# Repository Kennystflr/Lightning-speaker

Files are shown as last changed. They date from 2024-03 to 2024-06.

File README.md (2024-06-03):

# Lightning-speaker
Project of Kenny Saint Fleur, Mathys Minsac, Lavallee Alexandre, Florian Bonnet--Galand and Victor Morel. 1st Year ENSEA students.
Design of the electronic board for a speaker.
Using a STM32 microcontroller, audio codec and two class D amplifiers.

The purpose of this project is to design the electronic of a speaker. More specifically the goal is to take an entry signal from Jack 6.35 mm connector and to have sound coming out of a stereo loudspeaker. 
We could also have a parametric eq using 2 encoders 1 for the gain and 1 for the frequency we would be changing.
We also want to have the system working on battery with Usb-C power delivery to charge-up the battery and power up the system even if there is no battery connected.

There is a schematic of the projects detailed review on this repository's root. projectSchematics

Basically, we would be calcultating coeficients for the SGTL5000 audio codec with the STM32 from the encoder's command. We can command up to 4 different filters with this method.
Then we would apply filters to the audio codec by sending the filter's coeficients through I2C communication protocol to the SGTL5000.
About the signal itself, it would enter into the audio codec, pass through the filters, be transmitted to the STM32 using I2S communication protocol and then would go through the Half Bridge Class D audio amplifer.
To charge up the battery, the 9V power supply (negociated with a source by the STM32) goes through a BMS who can bypass the battery in case it is dead or missing.

An issue we have met doing this was that the Half bridge was commuting between a positive voltage and ground which was a bad for the loudspeakears as the load. To resolve that we had to cut the rms continuous voltage 
using a genuinely calculated capacity.

As IC references we have :
-Microprocessor : STM32G491CET6
-Audio codec :SGTL5000XNLA3
-Battery Management System : BQ25306RTET
- USB-C protection IC : TCPP01-M12
- USB protection IC : USBLC6-2SC6
- Mosfet driver : UCC27325DR
- LDO 5V : AZ1117-5.0
- LDO 3.3V : BU33SD5WG-TR
- LDO 1.8V : BU18SD5WG-TRe

Unfortunately, the project wouldn't work in the end and we weren't able to debug it before the due time.
So we came up with a lifeboat plan of showing off our secondary board :

Project Specifications for the Replacement Project (aims to test the different codes made during the project and the PCB secondary board):

To test the LEDs, the potentiometer, and the encoder button, the LEDs are lit one by one, faster or slower depending on the value of the potentiometer.
The button on encoder 1 allows the LEDs to light up in the opposite direction.

To test the RGB (even though we only use 2 out of 3 LEDs) and the rotation of the encoder, the brightness of the red LED of encoder 2 is increased while the brightness of the blue LED is decreased when encoder 1 is rotated in one direction and vice versa when rotated in the other direction.

As a bonus, pressing the button on encoder 1 toggles the green LED of encoder 1 on or off.

*There is an demonstration video on the repository's root* : FinalProjetDemo

To push the project further we could have :
- had a bluetooth connection with a phone app to control the features.
- used the USB-C port's FS USB connected to the STM32 to have had sound going into the loudspeaker from an extern device as a computer or even a smartphone...

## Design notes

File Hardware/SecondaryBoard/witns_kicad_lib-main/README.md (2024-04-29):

# WITNS Kicad Library

## Add to your project
```bash
git submodule add git@github.com:lfiack/witns_kicad_lib.git
```

## Don't forget to document your project
Add the following lines to your README.md :
````
## Make the project work
This project uses a submodule for the KiCAD library. To get it properly, use the `--recursive` option when cloning the repo :

```bash
git clone --recursive git@github.com:<path_to_your_project>
```

If you forgot the `--recursive` option (as I do quite often), you can type the following command :

```bash
git submodule update --init --recursive
```
````

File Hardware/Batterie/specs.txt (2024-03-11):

CODEC : "SGTL5000" : 3.3 V.
STM32 : "STM32G491CET6" : 3.3 V.
Mosfet driver : "UCC2732x" : 5 V.

2 Batteries 18650 de 3.6V ; 2500 mAh. -> 7.2 V
En série.
Battery Management System : puce "BQ25306".

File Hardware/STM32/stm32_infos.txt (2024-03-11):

Choix de la puce SMT32g491cet6.
On en a besoin pour implémenter pas mal de choses à la fois et l'on a qu'un format LQFP32 soit 32 pins.
On implémente dans la puce :
 - USB C power delivery
 - Encondage des potentiometres de réglage du codec en hexadecimal.
 - Renvoie des réglages potentiomètre vers le codec en protocole I2C.
 - Reception du signal audio modifié par le codec via le protocole I2S.
 - Sortie PWM du signal du codec Vers l'etage amplificateur avec un Timer.

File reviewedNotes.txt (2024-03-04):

Fabriquer une carte électronique pour remplacer celle du speaker de base (+ de prises Jack).
On a 2 haut parleur 2 Ohm 15W dans un caisson avec un ruban led (dont on ne connaît pas les spécificités )

Sous-systèmes :
A)Amplificateur audio -> Class-D -> mosfet drivers
B) CODEC Audio 
C)Circuit de charge de la batterie 7.2V (2* [3.6V,2600mAh] en série ) <- voir si on double le nombre de batteries pour les mettre en parallèle
D) Circuit pour le ruban led.

//////////////////////////////////////////////////////////////////////////////////////////////////////
Sous-système A : 
Avoir 1 jack 3.5 et un jack 6.35 en entrée
On a deux speakers 2 Ohm en parallèle donc une charge de 1 Ohms.
Donc à 15 W, V_Load_Max = 7,75V # V_Bat
Pour faire fonctionner les diffénents composants de l'amplificateur (Mosfet driver,Timer 555, AOPs ...), on a besoin d'un régulateur de tension 5V d'où le LM7805.

Etage Schématisé, reste a vérifier les valeurs des composants, puis à les choisir.
//////////////////////////////////////////////////////////////////////////////////////////////////////
 Sous-Système B :
Pour appliquer des modifications au signal analogique d'entrée, on utilise le CODEC Audio SGTL5000. On utilisera les features d'equalisation (PEQ ou GEQ), controle du niveau de volume et bass boost.

//////////////////////////////////////////////////////////////////////////////////////////////////////
Sous-système C : 
La batterie est pour l'instant composée de deux cellules 18650(3.6V, 2600mAh) en série.
Charge USB C -> Puce Power delivery : TPS25730 + BMS IC : BQ25798 
on mettra juste un port usb c avec tout ça.

//////////////////////////////////////////////////////////////////////////////////////////////////////
Sous-système D :
Voir technologie Neopixel : https://github.com/berndoJ/libneopixel32/tree/master

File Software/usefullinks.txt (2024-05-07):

Flash memory to store the settings between use of the speaker :
https://www.st.com/resource/en/product_training/STM32G4-Memory-Flash_FLASH.pdf

Examples of USB C power Delivery implementation :
https://github.com/STMicroelectronics/STM32CubeG4/tree/master/Projects/B-G474E-DPOW1/Applications/USB-PD/USB-PD_Consumer_1port
https://www.youtube.com/watch?v=-vsJhNIaHxE

SGTL5000 audio codec implementation :
https://github.com/PaulStoffregen/Audio/blob/master/control_sgtl5000.cpp#L977

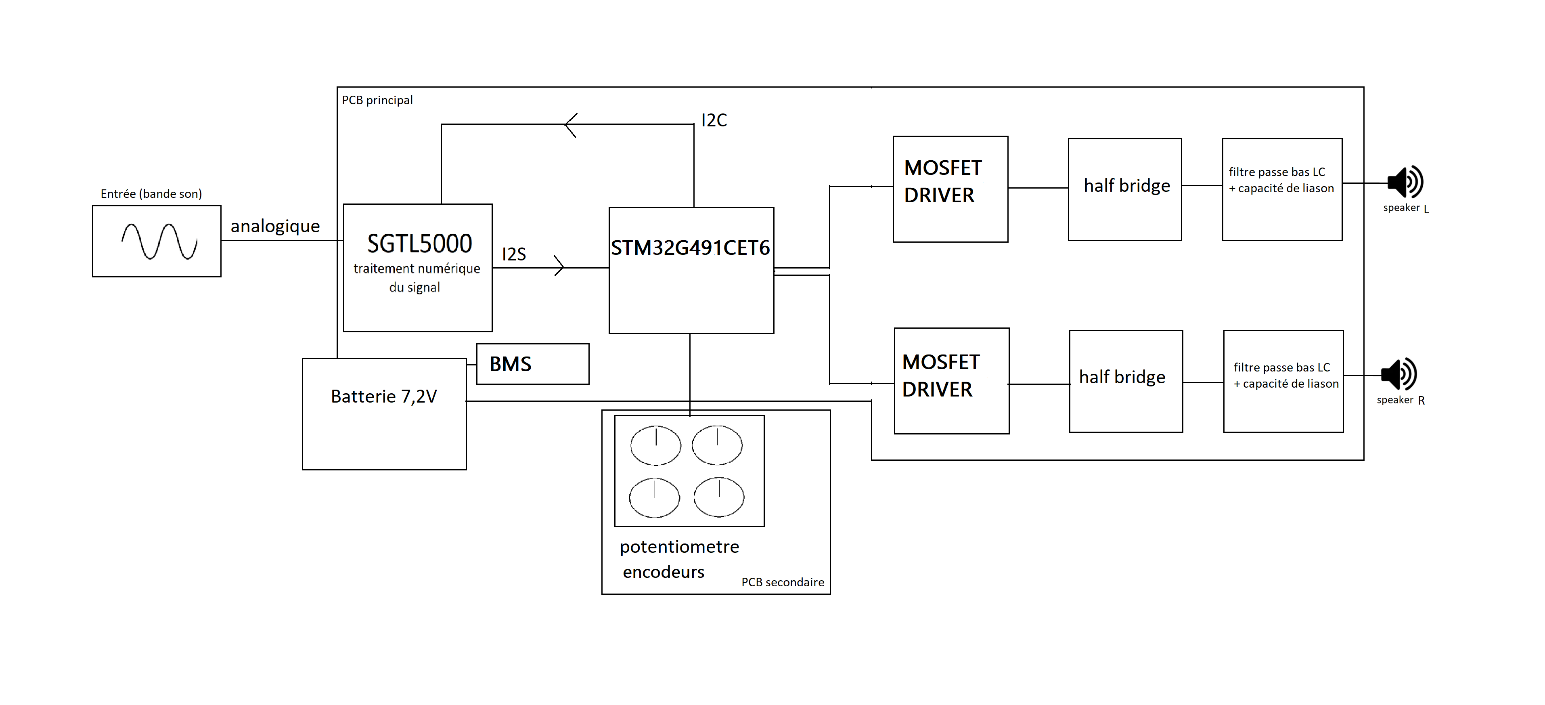
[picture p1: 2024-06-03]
projectSchematics.png

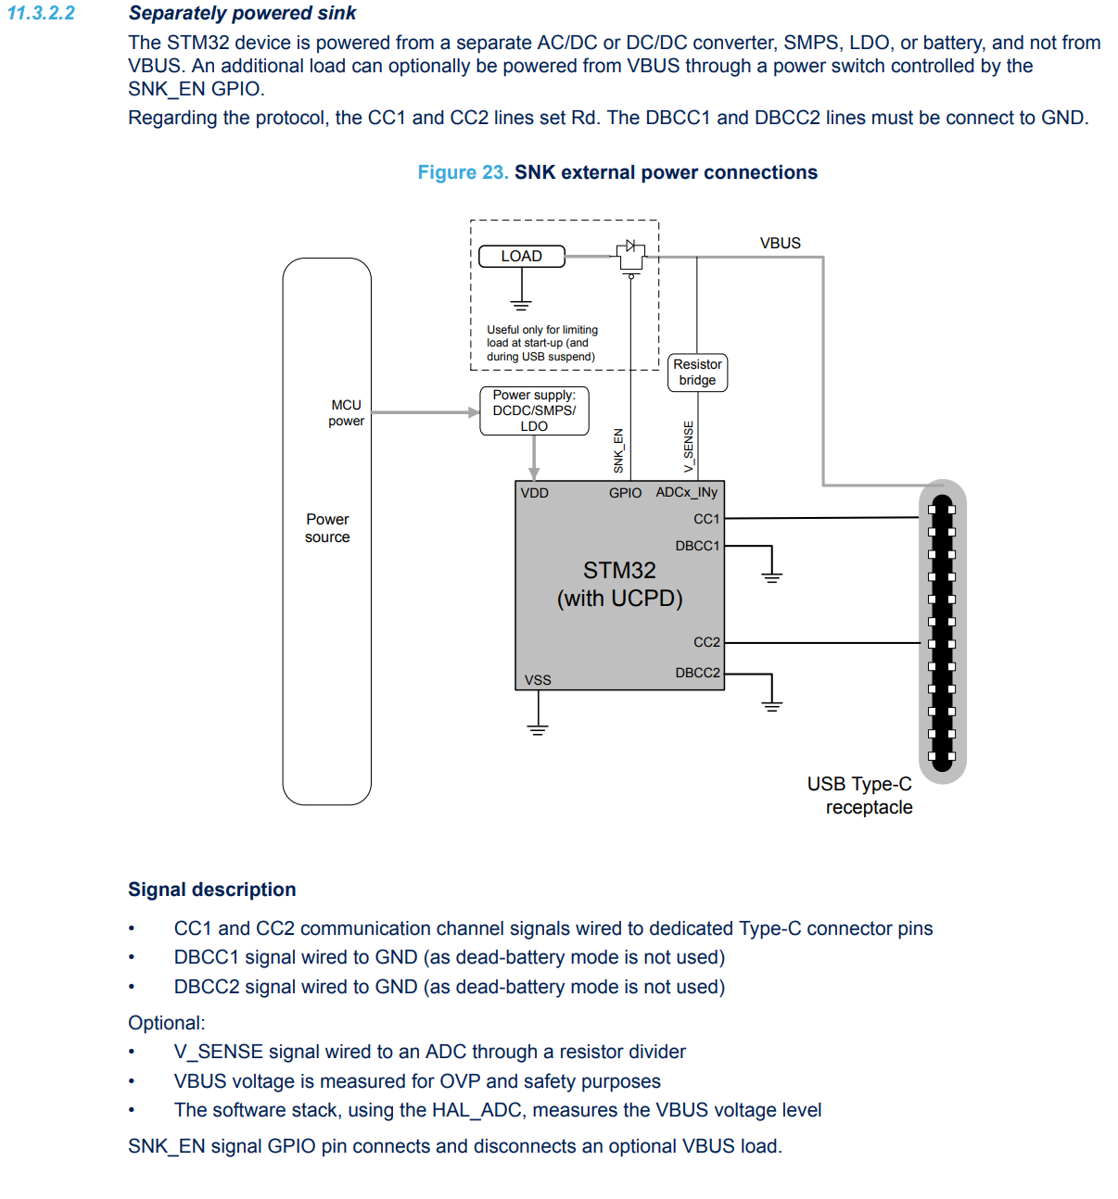
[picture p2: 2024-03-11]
Hardware/Batterie/USBCPD/Schematic.PNG

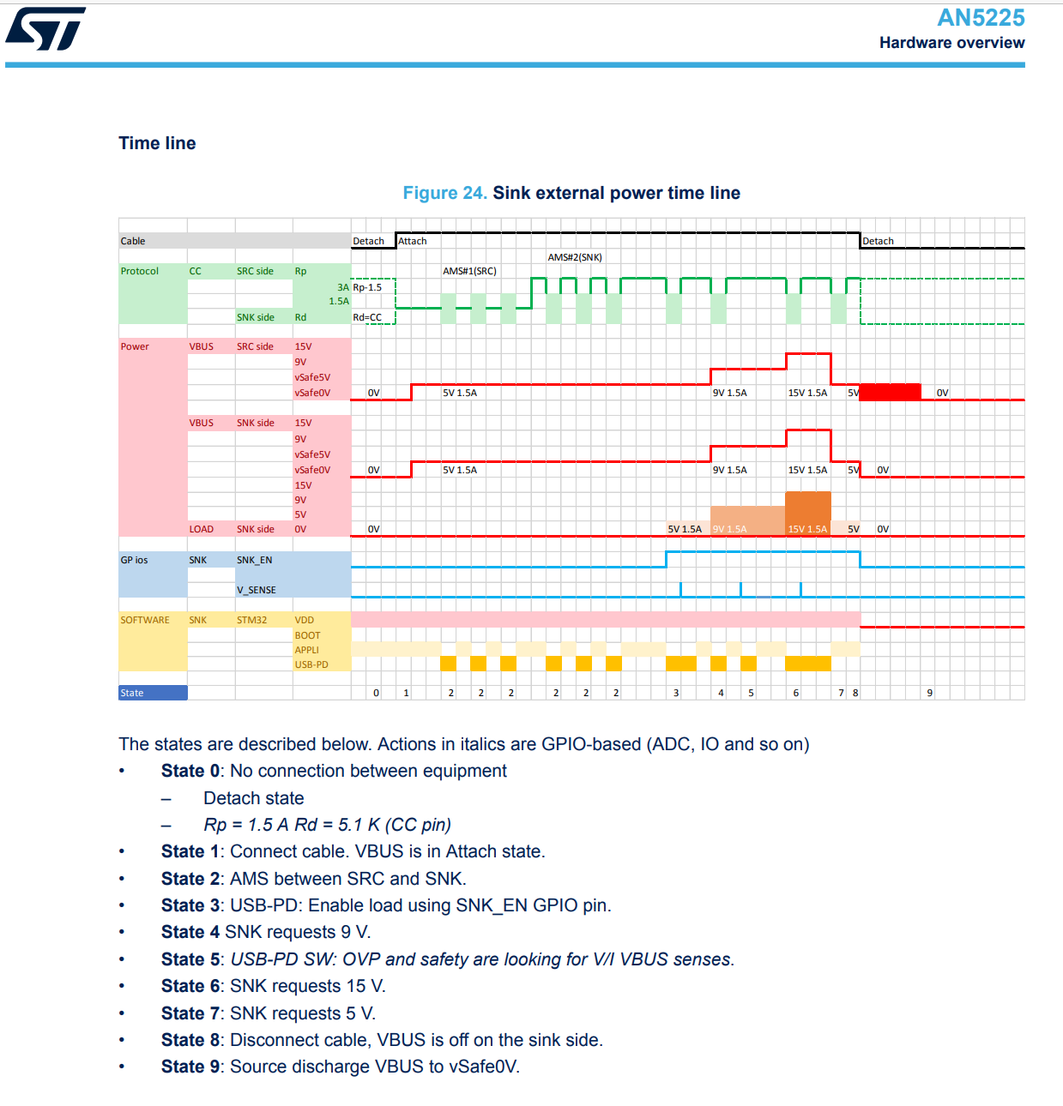
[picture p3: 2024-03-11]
Hardware/Batterie/USBCPD/states.PNG

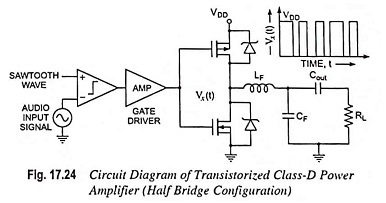
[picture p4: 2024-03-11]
Hardware/Circuit-Diagram-of-Transistorized-Class-D-Power-Amplifier-Half-Bridge-Configuration-02.jpg

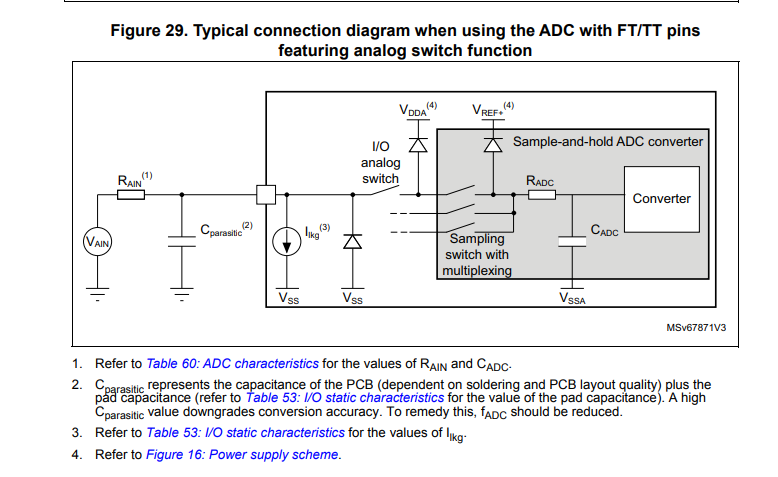
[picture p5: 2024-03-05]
Hardware/Potentiometre/SchémaSTM32p132.PNG

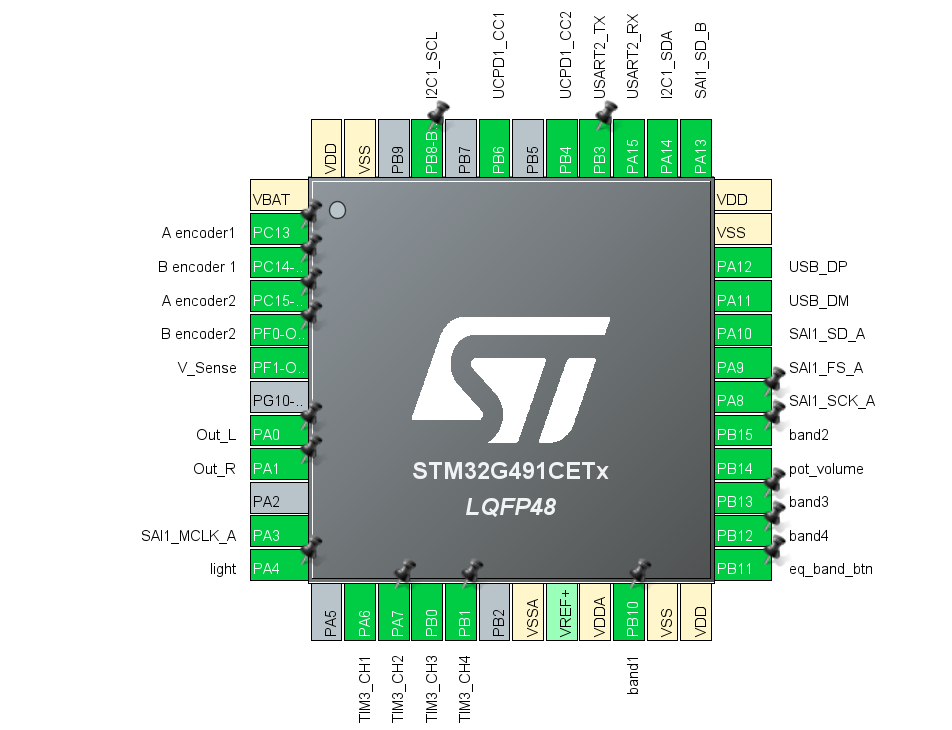
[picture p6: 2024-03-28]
Hardware/STM32/FinalPinout.PNG

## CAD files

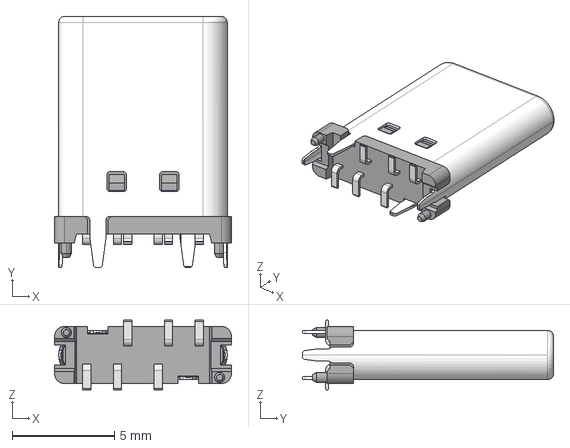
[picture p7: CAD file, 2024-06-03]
Hardware/Mainboard Final/footprints/USB4180-03-0120-C_REVA.step
8.66 x 12.3 x 3.40 mm

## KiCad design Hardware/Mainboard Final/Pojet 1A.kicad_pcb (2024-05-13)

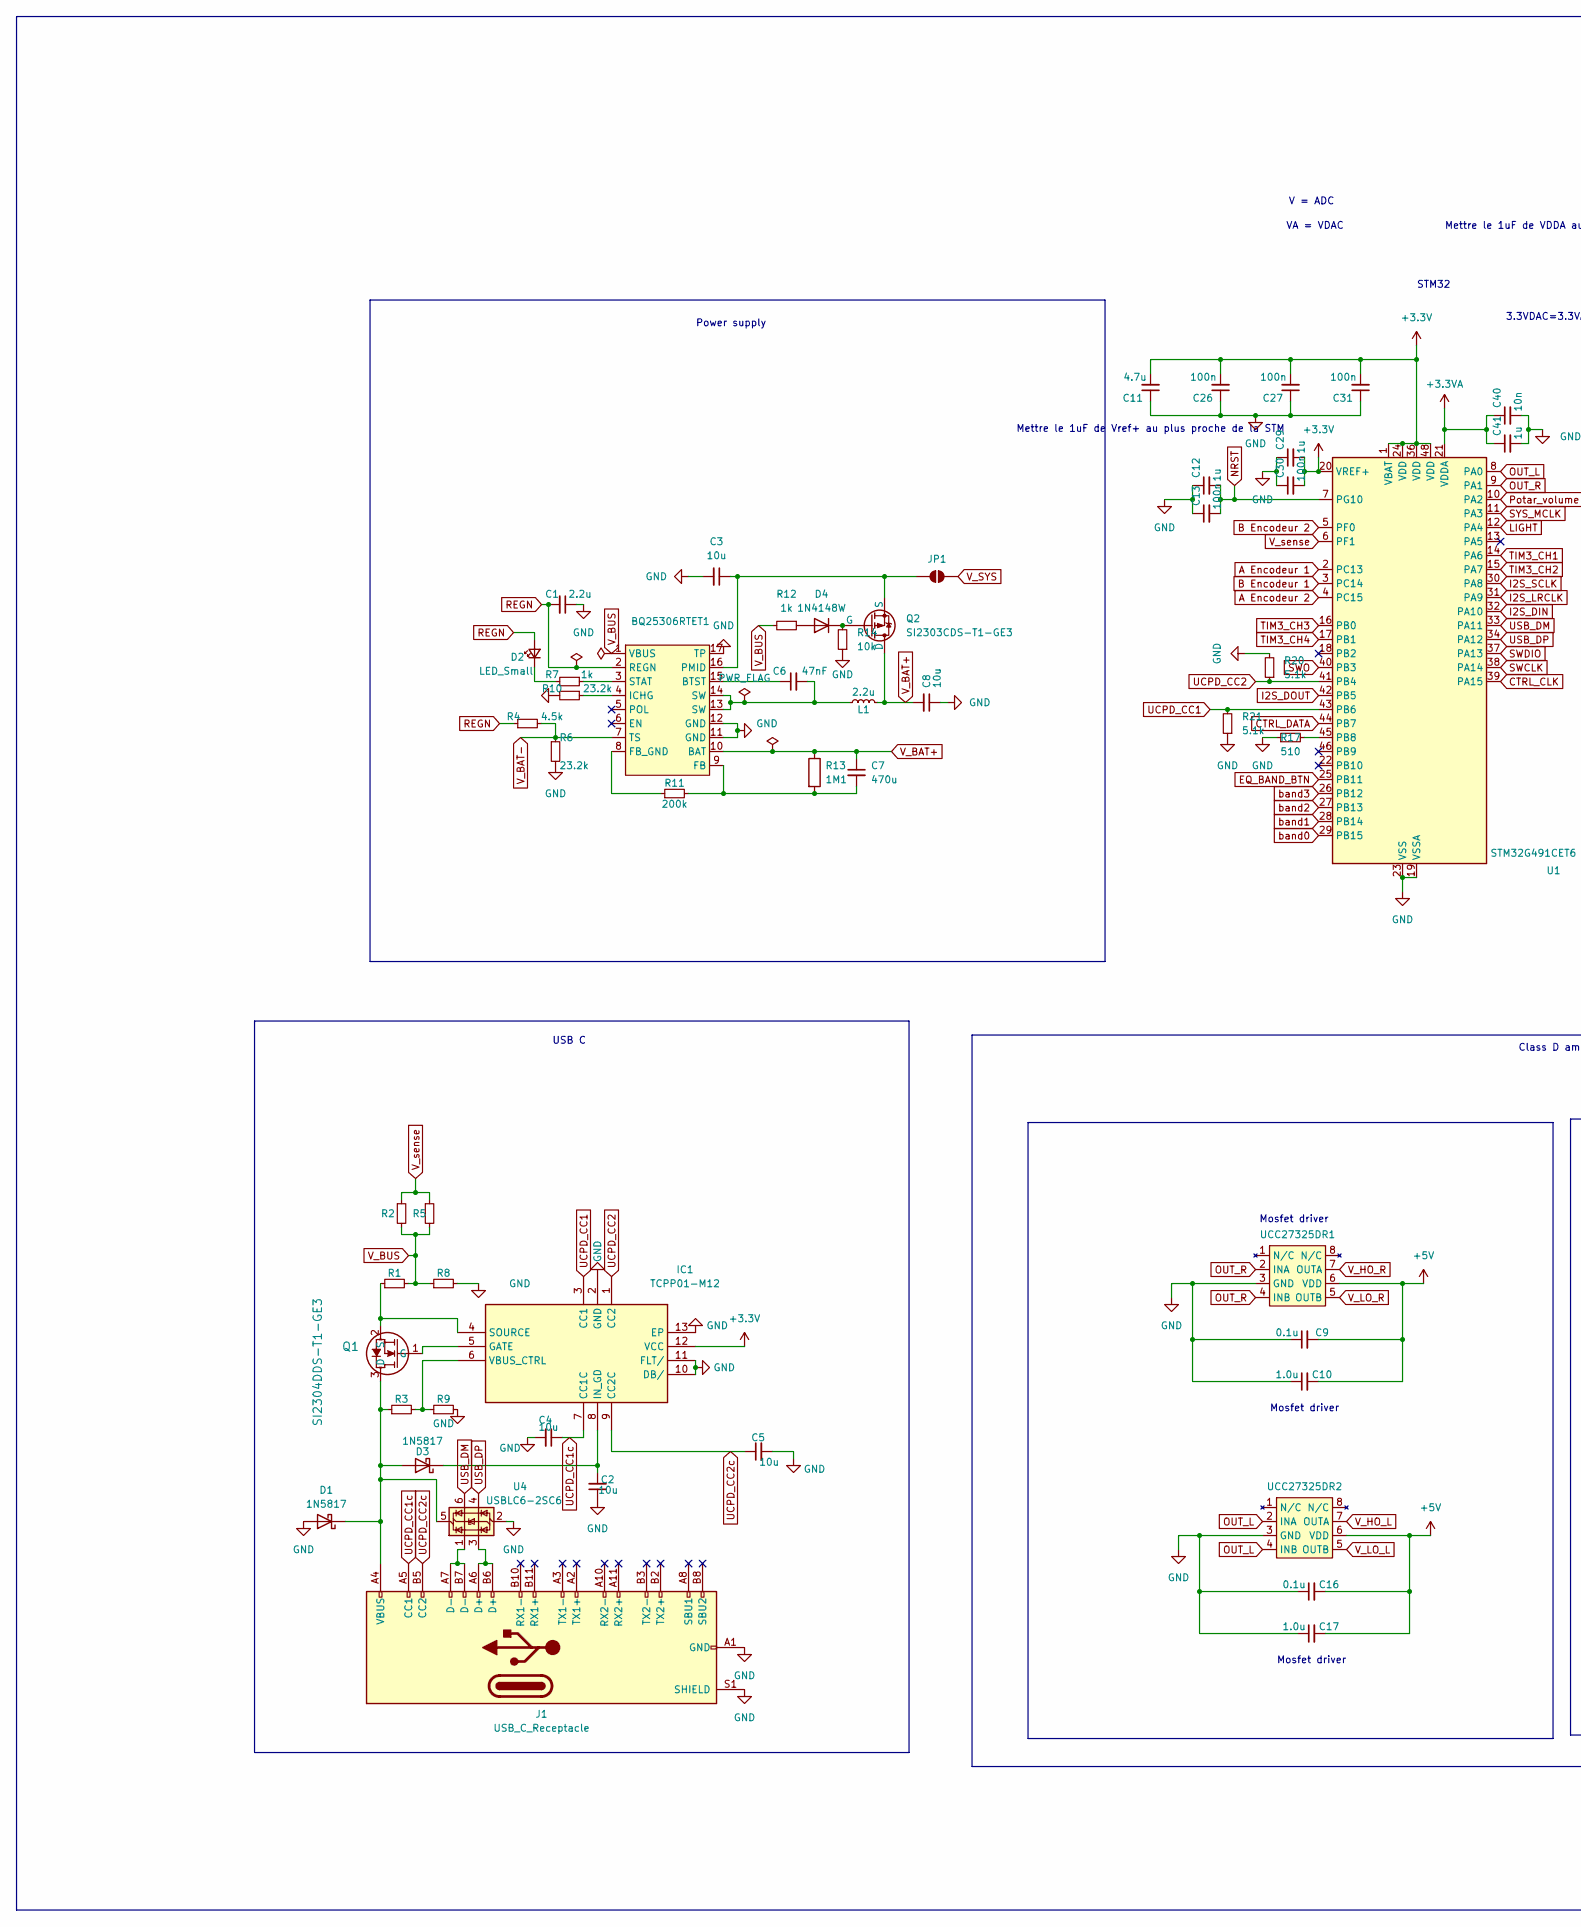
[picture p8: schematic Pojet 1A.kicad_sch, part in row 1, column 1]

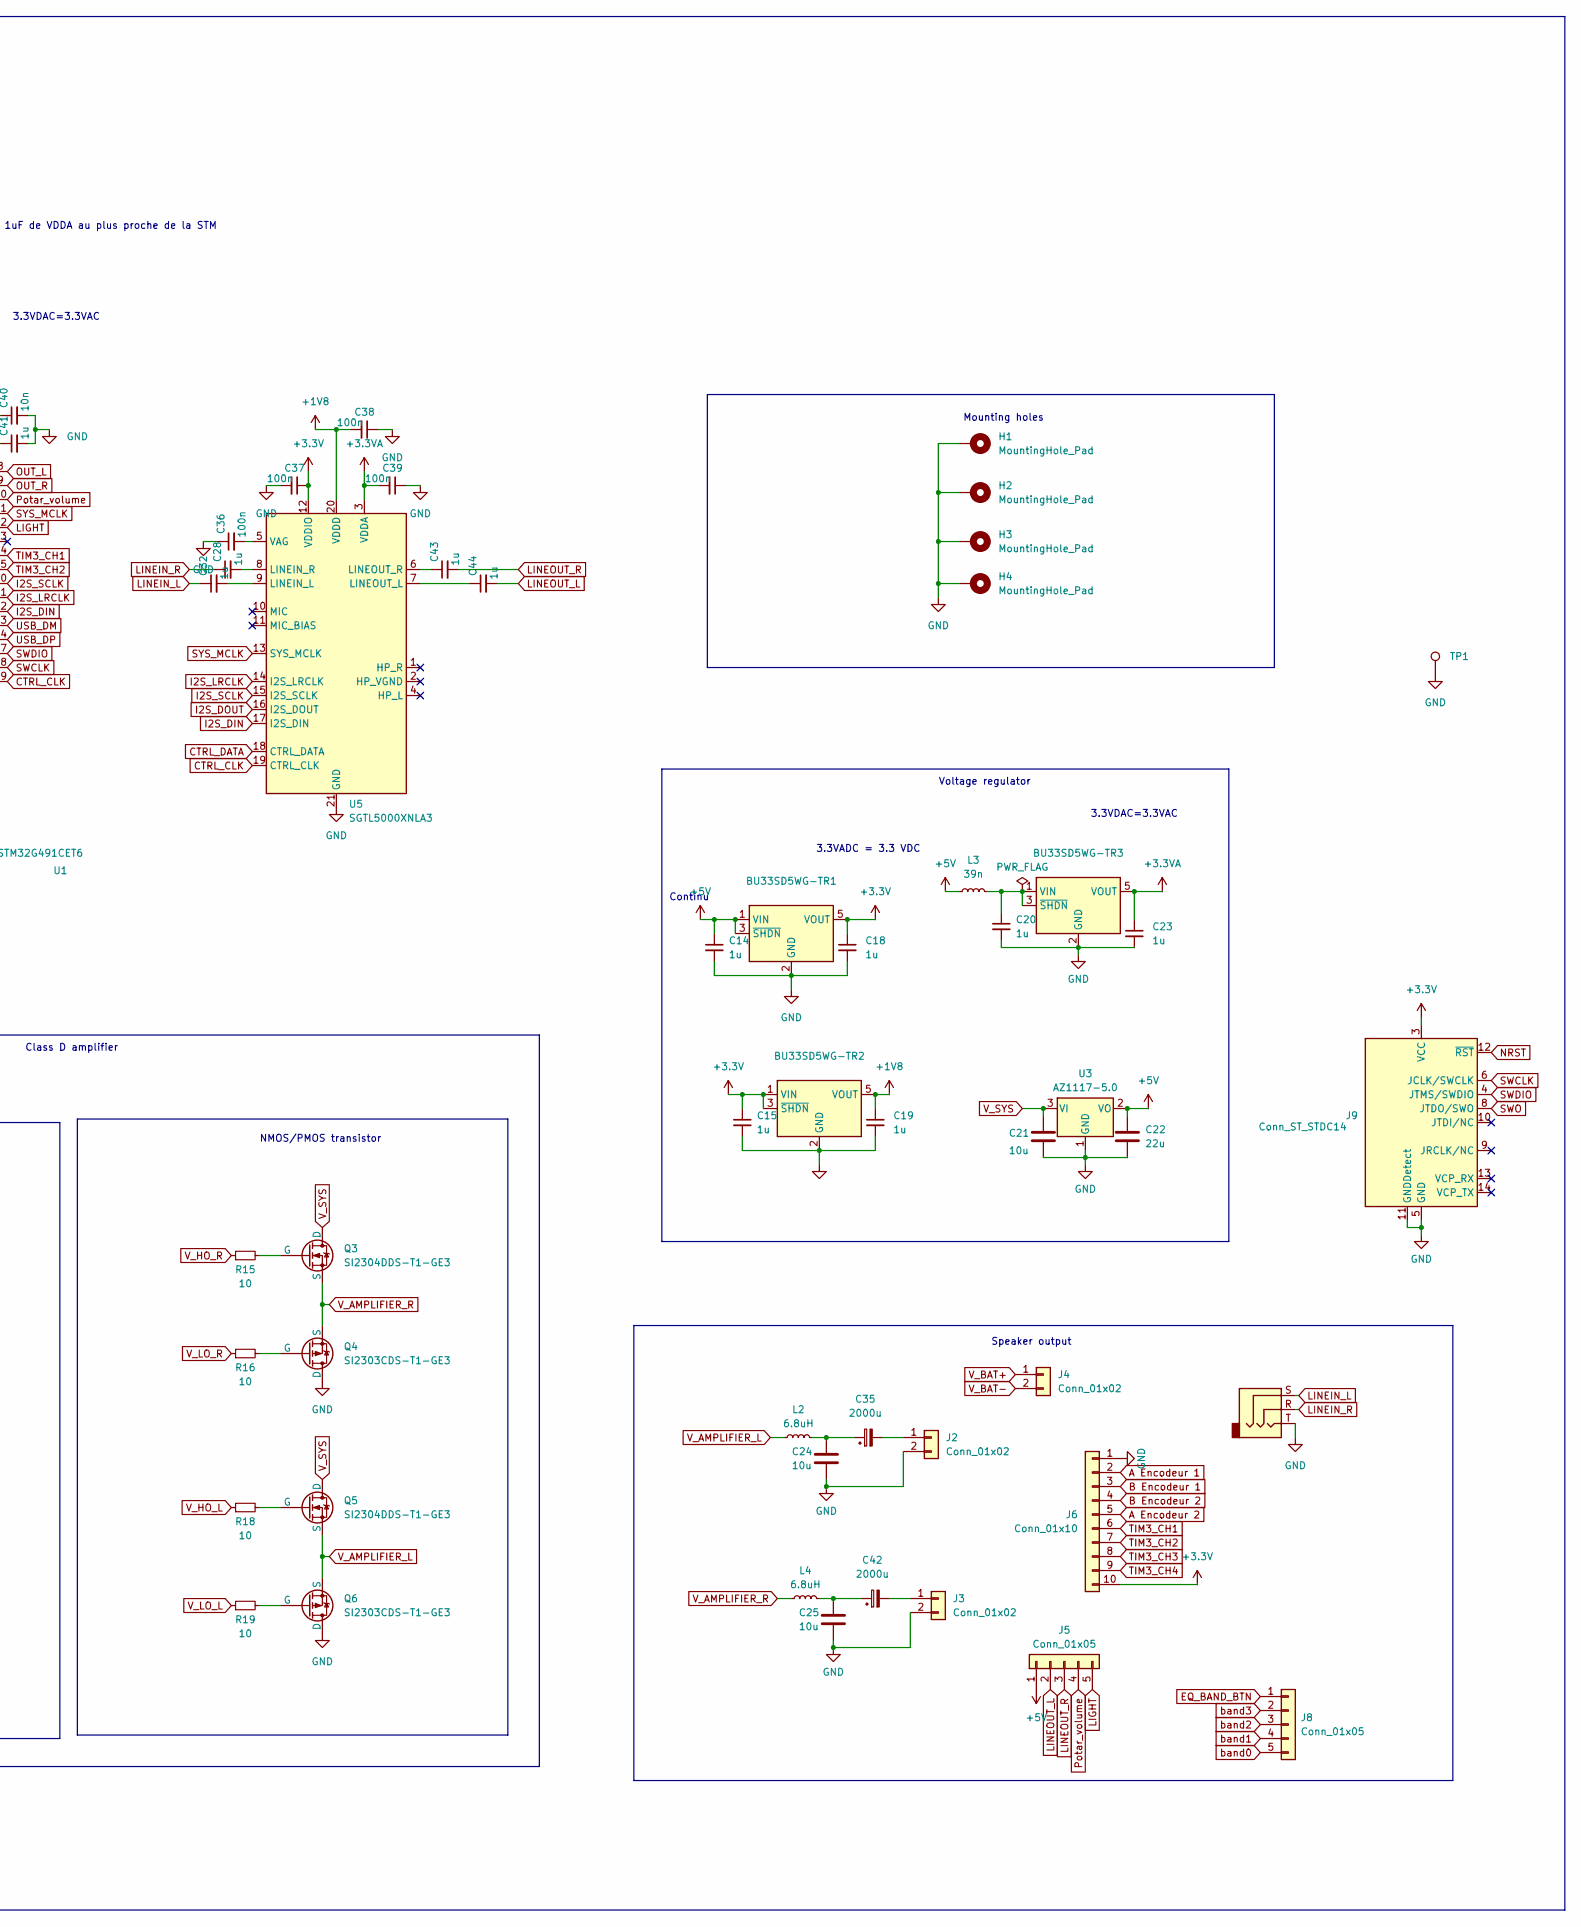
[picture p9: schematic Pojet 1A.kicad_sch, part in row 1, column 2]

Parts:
BQ25306RTET1: WQFN-16-1EP_3x3mm_P0.5mm_EP1.75x1.75mm
BU33SD5WG-TR1, BU33SD5WG-TR2, BU33SD5WG-TR3: LM1117DT-3.3; SOT-23-5
C1: 2.2u; C_0603_1608Metric_Pad1.08x0.95mm_HandSolder
C2, C3, C4, C5, C8, C24, C25: 10u; C_0402_1005Metric_Pad0.74x0.62mm_HandSolder
C6: 47nF; C_0603_1608Metric_Pad1.08x0.95mm_HandSolder
C7: 470u; C_0603_1608Metric_Pad1.08x0.95mm_HandSolder
C9, C16: 0.1u; C_0603_1608Metric_Pad1.08x0.95mm_HandSolder
C10, C17: 1.0u; C_0603_1608Metric_Pad1.08x0.95mm_HandSolder
C11: 4.7u; C_0603_1608Metric_Pad1.08x0.95mm_HandSolder
C12, C14, C15, C18, C19, C20, C23, C28, C29, C32, C41, C43, C44: 1u; C_0603_1608Metric_Pad1.08x0.95mm_HandSolder
C13, C26, C27, C30, C31, C36, C37, C38, C39: 100n; C_0402_1005Metric_Pad0.74x0.62mm_HandSolder
C21: 10u; C_0603_1608Metric_Pad1.08x0.95mm_HandSolder
C22: 22u; C_0805_2012Metric_Pad1.18x1.45mm_HandSolder
C35, C42: 2000u; CP_Radial_D10.0mm_P5.00mm
C40: 10n; C_0402_1005Metric_Pad0.74x0.62mm_HandSolder
D1, D3: 1N5817; D_DO-41_SOD81_P10.16mm_Horizontal
D2: LED_Small; LED_D5.0mm_IRGrey
D4: 1N4148W; D_SOD-123
H1, H2, H3, H4: MountingHole_Pad; MountingHole_3.2mm_M3_DIN965_Pad
IC1: TCPP01-M12; LQFN-12-1EP_2x2mm_P0.5mm_EP0.7x0.7mm; Manufacturer_Part_Number TCPP01-M12; Mouser Part Number 511-TCPP01-M12
J1: USB_C_Receptacle; USB_C_Receptacle_GCT_USB4115-03-C
J2, J3, J4: Conn_01x02; JST_XH_B2B-XH-A_1x02_P2.50mm_Vertical
J5, J8: Conn_01x05; PinHeader_1x05_P2.54mm_Vertical
J6: Conn_01x10; PinHeader_1x10_P2.54mm_Vertical
J7: AudioJack3; Jack_6.35mm_Neutrik_NJ3FD-V_Vertical
J9: Conn_ST_STDC14; PinHeader_2x07_P1.27mm_Vertical_SMD
JP1: SolderJumper_2_Open; SolderJumper-2_P1.3mm_Open_TrianglePad1.0x1.5mm
L1: 2.2u; L_0603_1608Metric_Pad1.05x0.95mm_HandSolder
L2, L4: 6.8uH; L_0603_1608Metric_Pad1.05x0.95mm_HandSolder
L3: 39n; L_0603_1608Metric_Pad1.05x0.95mm_HandSolder
Q1, Q3, Q5: SI2304DDS-T1-GE3; SOT-23
Q2, Q4, Q6: SI2303CDS-T1-GE3; SOT-23
R1, R2, R3, R5, R8, R9: R_0603_1608Metric_Pad0.98x0.95mm_HandSolder
R4: 4.5k; R_0603_1608Metric_Pad0.98x0.95mm_HandSolder
R6, R10: 23.2k; R_0603_1608Metric_Pad0.98x0.95mm_HandSolder
R7, R12: 1k; R_0603_1608Metric_Pad0.98x0.95mm_HandSolder
R11: 200k; R_0603_1608Metric_Pad0.98x0.95mm_HandSolder
R13: 1M1; R_0603_1608Metric_Pad0.98x0.95mm_HandSolder
R14: 10k; R_0603_1608Metric_Pad0.98x0.95mm_HandSolder
R15, R16, R18, R19: 10; R_0603_1608Metric_Pad0.98x0.95mm_HandSolder
R17: 510; R_0603_1608Metric_Pad0.98x0.95mm_HandSolder
R20, R21: 5.1k; R_0402_1005Metric_Pad0.72x0.64mm_HandSolder
TP1: TestPoint; TestPoint_Pad_D2.0mm
U1: STM32G491CET6; LQFP-48_7x7mm_P0.5mm
U3: AZ1117-5.0; SOT-223-3_TabPin2
U4: USBLC6-2SC6; SOT-23-6
U5: SGTL5000XNLA3; QFN-20-1EP_3x3mm_P0.4mm_EP1.65x1.65mm
UCC27325DR1, UCC27325DR2: SOIC-8_3.9x4.9mm_P1.27mm

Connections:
+1V8: BU33SD5WG-TR2.5 (VOUT), C19.1, C38.2, U5.20 (VDDD)
+3.3V: BU33SD5WG-TR1.5 (VOUT), BU33SD5WG-TR2.1 (VIN), BU33SD5WG-TR2.3 (~SHDN), C11.2, C15.1, C18.1, C26.2, C27.2, C29.2, C30.2, C31.2, C37.1, IC1.12 (VCC), J6.10, J9.3 (VCC), U1.1 (VBAT), U1.20 (VREF+), U1.24 (VDD), U1.36 (VDD), U1.48 (VDD), U5.12 (VDDIO)
+3.3VA: BU33SD5WG-TR3.5 (VOUT), C23.1, C39.2, C40.1, C41.1, U1.21 (VDDA), U5.3 (VDDA)
+5V: BU33SD5WG-TR1.1 (VIN), BU33SD5WG-TR1.3 (~SHDN), C9.2, C10.2, C14.1, C16.2, C17.2, C22.1, J5.1, L3.1, U3.2 (VO), UCC27325DR1.6 (VDD), UCC27325DR2.6 (VDD)
A Encodeur 1: J6.2, U1.2 (PC13)
A Encodeur 2: J6.5, U1.4 (PC15)
B Encodeur 1: J6.3, U1.3 (PC14)
B Encodeur 2: J6.4, U1.5 (PF0)
CTRL_CLK: U1.39 (PA15), U5.19 (CTRL_CLK)
CTRL_DATA: U1.44 (PB7), U5.18 (CTRL_DATA)
EQ_BAND_BTN: J8.1, U1.25 (PB11)
GND: BQ25306RTET1.11 (GND), BQ25306RTET1.12 (GND), BQ25306RTET1.17 (TP), BU33SD5WG-TR1.2 (GND), BU33SD5WG-TR2.2 (GND), BU33SD5WG-TR3.2 (GND), C1.1, C2.1, C3.2, C4.2, C5.2, C8.1, C9.1, C10.1, C11.1, C12.1, C13.1, C14.2, C15.2, C16.1, C17.1, C18.2, C19.2, C20.2, C21.2, C22.2, C23.2, C24.2, C25.2, C26.1, C27.1, C29.1, C30.1, C31.1, C36.1, C37.2, C38.1, C39.1, C40.2, C41.2, D1.2 (A), H1.1, H2.1, H3.1, H4.1, IC1.2 (GND), IC1.10 (DB/), IC1.11 (FLT/), IC1.13 (EP), J1.A1 (GND), J1.A12 (GND), J1.B1 (GND), J1.B12 (GND), J1.S1 (SHIELD), J2.2, J3.2, J6.1, J7.T, J9.5 (GND), J9.7 (GND), J9.11 (GNDDetect), Q4.1 (D), Q6.1 (D), R6.2, R8.2, R9.2, R10.2, R14.1, R17.1, R20.2, R21.1, TP1.1, U1.19 (VSSA), U1.23 (VSS), U1.35 (VSS), U1.47 (VSS), U3.1 (GND), U4.2 (GND), U5.21 (GND), UCC27325DR1.3 (GND), UCC27325DR2.3 (GND)
I2S_DIN: U1.32 (PA10), U5.17 (I2S_DIN)
I2S_DOUT: U1.42 (PB5), U5.16 (I2S_DOUT)
I2S_LRCLK: U1.31 (PA9), U5.14 (I2S_LRCLK)
I2S_SCLK: U1.30 (PA8), U5.15 (I2S_SCLK)
LIGHT: J5.5, U1.12 (PA4)
LINEIN_L: C32.1, J7.S
LINEIN_R: C28.1, J7.R
LINEOUT_L: C44.2, J5.2
LINEOUT_R: C43.2, J5.3
NRST: C12.2, C13.2, J9.12 (~RST), U1.7 (PG10)
unnamed: BQ25306RTET1.15 (BTST), C6.1
unnamed: BQ25306RTET1.9 (FB), C7.2, R11.2, R13.2
unnamed: BQ25306RTET1.8 (FB_GND), R11.1
unnamed: BQ25306RTET1.4 (ICHG), R10.1
unnamed: BQ25306RTET1.16 (PMID), C3.1, JP1.1 (A), Q2.3 (S)
unnamed: BQ25306RTET1.3 (STAT), R7.1
unnamed: BQ25306RTET1.13 (SW), BQ25306RTET1.14 (SW), C6.2, L1.1
unnamed: BU33SD5WG-TR3.1 (VIN), BU33SD5WG-TR3.3 (~SHDN), C20.1, L3.2
unnamed: C24.1, C35.1, L2.2
unnamed: C25.1, C42.1, L4.2
unnamed: D1.1 (K), D3.2 (A), J1.A4 (VBUS), J1.A9 (VBUS), J1.B4 (VBUS), J1.B9 (VBUS), Q1.3 (D), R3.1, U4.5 (VBUS)
unnamed: D2.1 (K), R7.2
unnamed: C2.2, D3.1 (K), IC1.8 (IN_GD)
unnamed: D4.2 (A), R12.1
unnamed: D4.1 (K), Q2.2 (G), R14.2
unnamed: IC1.5 (GATE), Q1.1 (G)
unnamed: IC1.4 (SOURCE), Q1.2 (S), R1.1
unnamed: IC1.6 (VBUS_CTRL), R3.2, R9.1
unnamed: J1.A6 (D+), J1.B6 (D+), U4.3 (I/O2)
unnamed: J1.A7 (D-), J1.B7 (D-), U4.1 (I/O1)
unnamed: C35.2, J2.1
unnamed: C42.2, J3.1
unnamed: Q3.2 (G), R15.2
unnamed: Q4.2 (G), R16.2
unnamed: Q5.2 (G), R18.2
unnamed: Q6.2 (G), R19.2
unnamed: R17.2, U1.45 (PB8)
unnamed: C32.2, U5.9 (LINEIN_L)
unnamed: C28.2, U5.8 (LINEIN_R)
unnamed: C44.1, U5.7 (LINEOUT_L)
unnamed: C43.1, U5.6 (LINEOUT_R)
unnamed: C36.2, U5.5 (VAG)
OUT_L: U1.8 (PA0), UCC27325DR2.2 (INA), UCC27325DR2.4 (INB)
OUT_R: U1.9 (PA1), UCC27325DR1.2 (INA), UCC27325DR1.4 (INB)
Potar_volume: J5.4, U1.10 (PA2)
REGN: BQ25306RTET1.2 (REGN), C1.2, D2.2 (A), R4.1
SWCLK: J9.6 (JCLK/SWCLK), U1.38 (PA14)
SWDIO: J9.4 (JTMS/SWDIO), U1.37 (PA13)
SWO: J9.8 (JTDO/SWO), U1.40 (PB3)
SYS_MCLK: U1.11 (PA3), U5.13 (SYS_MCLK)
TIM3_CH1: J6.6, U1.14 (PA6)
TIM3_CH2: J6.7, U1.15 (PA7)
TIM3_CH3: J6.8, U1.16 (PB0)
TIM3_CH4: J6.9, U1.17 (PB1)
UCPD_CC1: IC1.3 (CC1), R21.2, U1.43 (PB6)
UCPD_CC1c: C4.1, IC1.7 (CC1C), J1.A5 (CC1)
UCPD_CC2: IC1.1 (CC2), R20.1, U1.41 (PB4)
UCPD_CC2c: C5.1, IC1.9 (CC2C), J1.B5 (CC2)
USB_DM: U1.33 (PA11), U4.6 (I/O1)
USB_DP: U1.34 (PA12), U4.4 (I/O2)
V_AMPLIFIER_L: L2.1, Q5.3 (S), Q6.3 (S)
V_AMPLIFIER_R: L4.1, Q3.3 (S), Q4.3 (S)
V_BAT+: BQ25306RTET1.10 (BAT), C7.1, C8.2, J4.1, L1.2, Q2.1 (D), R13.1
V_BAT-: BQ25306RTET1.7 (TS), J4.2, R4.2, R6.1
V_BUS: BQ25306RTET1.1 (VBUS), R1.2, R2.2, R5.2, R8.1, R12.2
V_HO_L: R18.1, UCC27325DR2.7 (OUTA)
V_HO_R: R15.1, UCC27325DR1.7 (OUTA)
V_LO_L: R19.1, UCC27325DR2.5 (OUTB)
V_LO_R: R16.1, UCC27325DR1.5 (OUTB)
V_SYS: C21.1, JP1.2 (B), Q3.1 (D), Q5.1 (D), U3.3 (VI)
V_sense: R2.1, R5.1, U1.6 (PF1)
band0: J8.5, U1.29 (PB15)
band1: J8.4, U1.28 (PB14)
band2: J8.3, U1.27 (PB13)
band3: J8.2, U1.26 (PB12)

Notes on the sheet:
Class D amplifier
V = ADC
Power supply
Mounting holes
Mettre le 1uF de VDDA au plus proche de la STM
Voltage regulator
Mosfet driver
USB C
3.3VDAC=3.3VAC
VA = VDAC
Mettre le 1uF de Vref+ au plus proche de la STM
NMOS/PMOS transistor
Speaker output
STM32
3.3VADC = 3.3 VDC
Continu

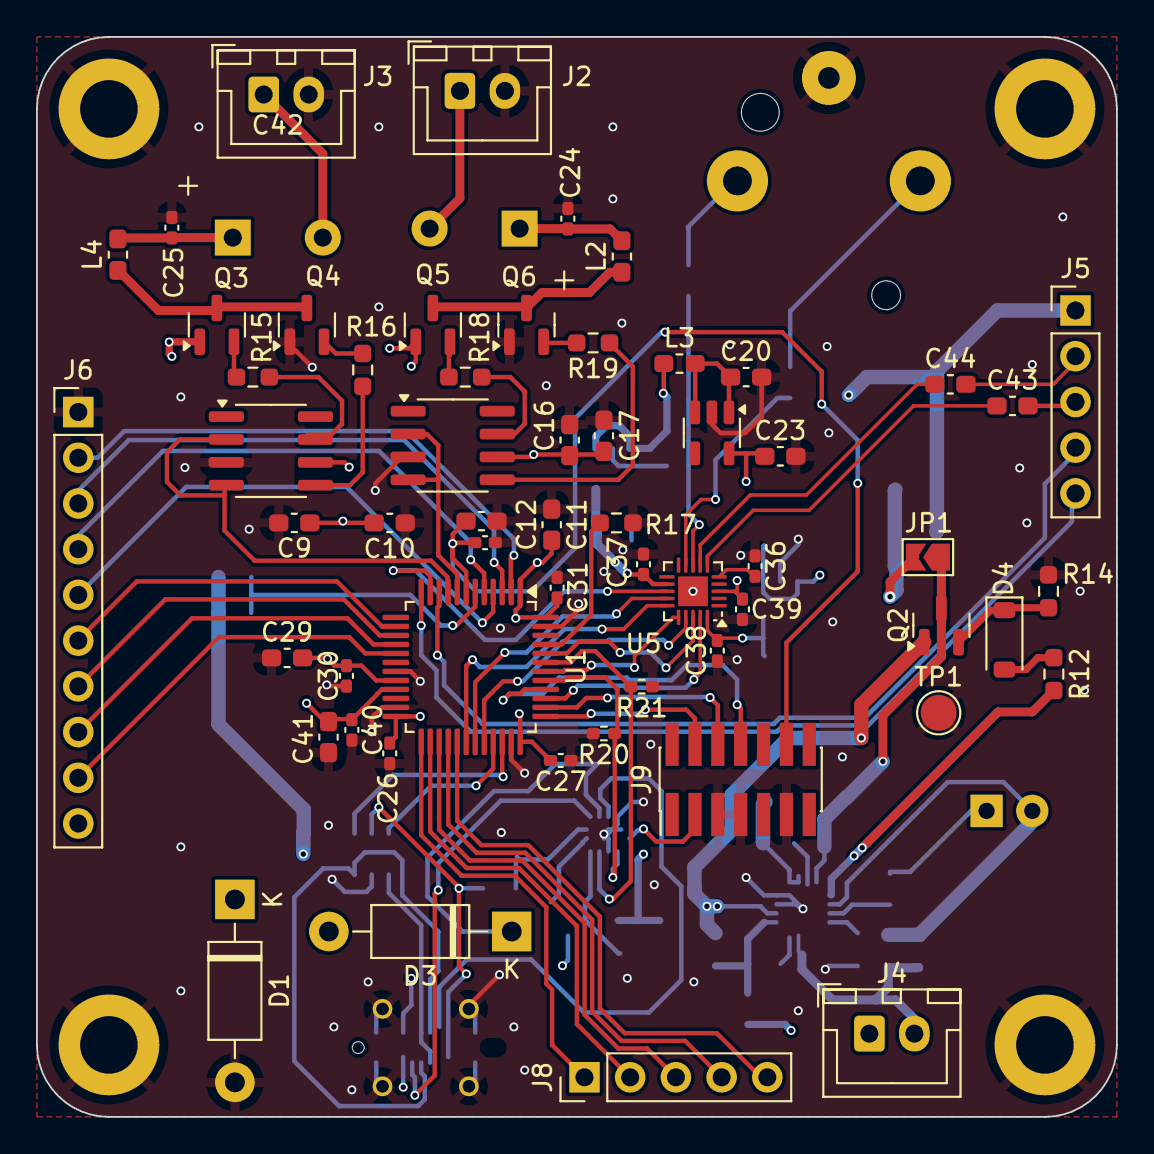
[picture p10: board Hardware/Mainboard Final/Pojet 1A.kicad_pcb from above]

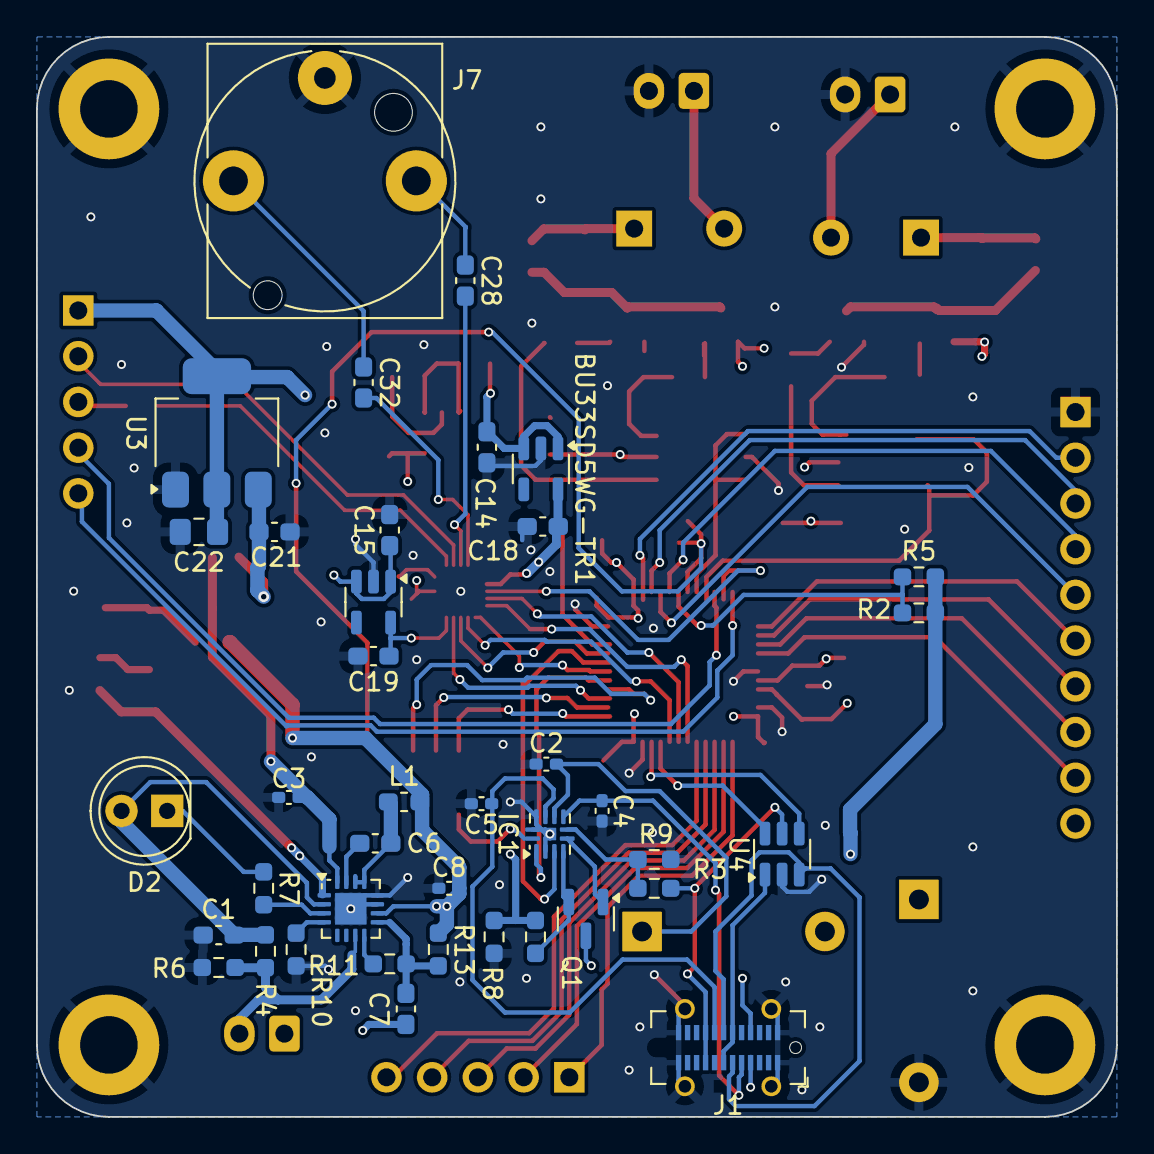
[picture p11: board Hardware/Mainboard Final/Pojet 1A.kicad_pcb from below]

Board: 4 copper layers, 60.0 x 60.0 mm, 103 parts (39 on the bottom side), 87 nets.

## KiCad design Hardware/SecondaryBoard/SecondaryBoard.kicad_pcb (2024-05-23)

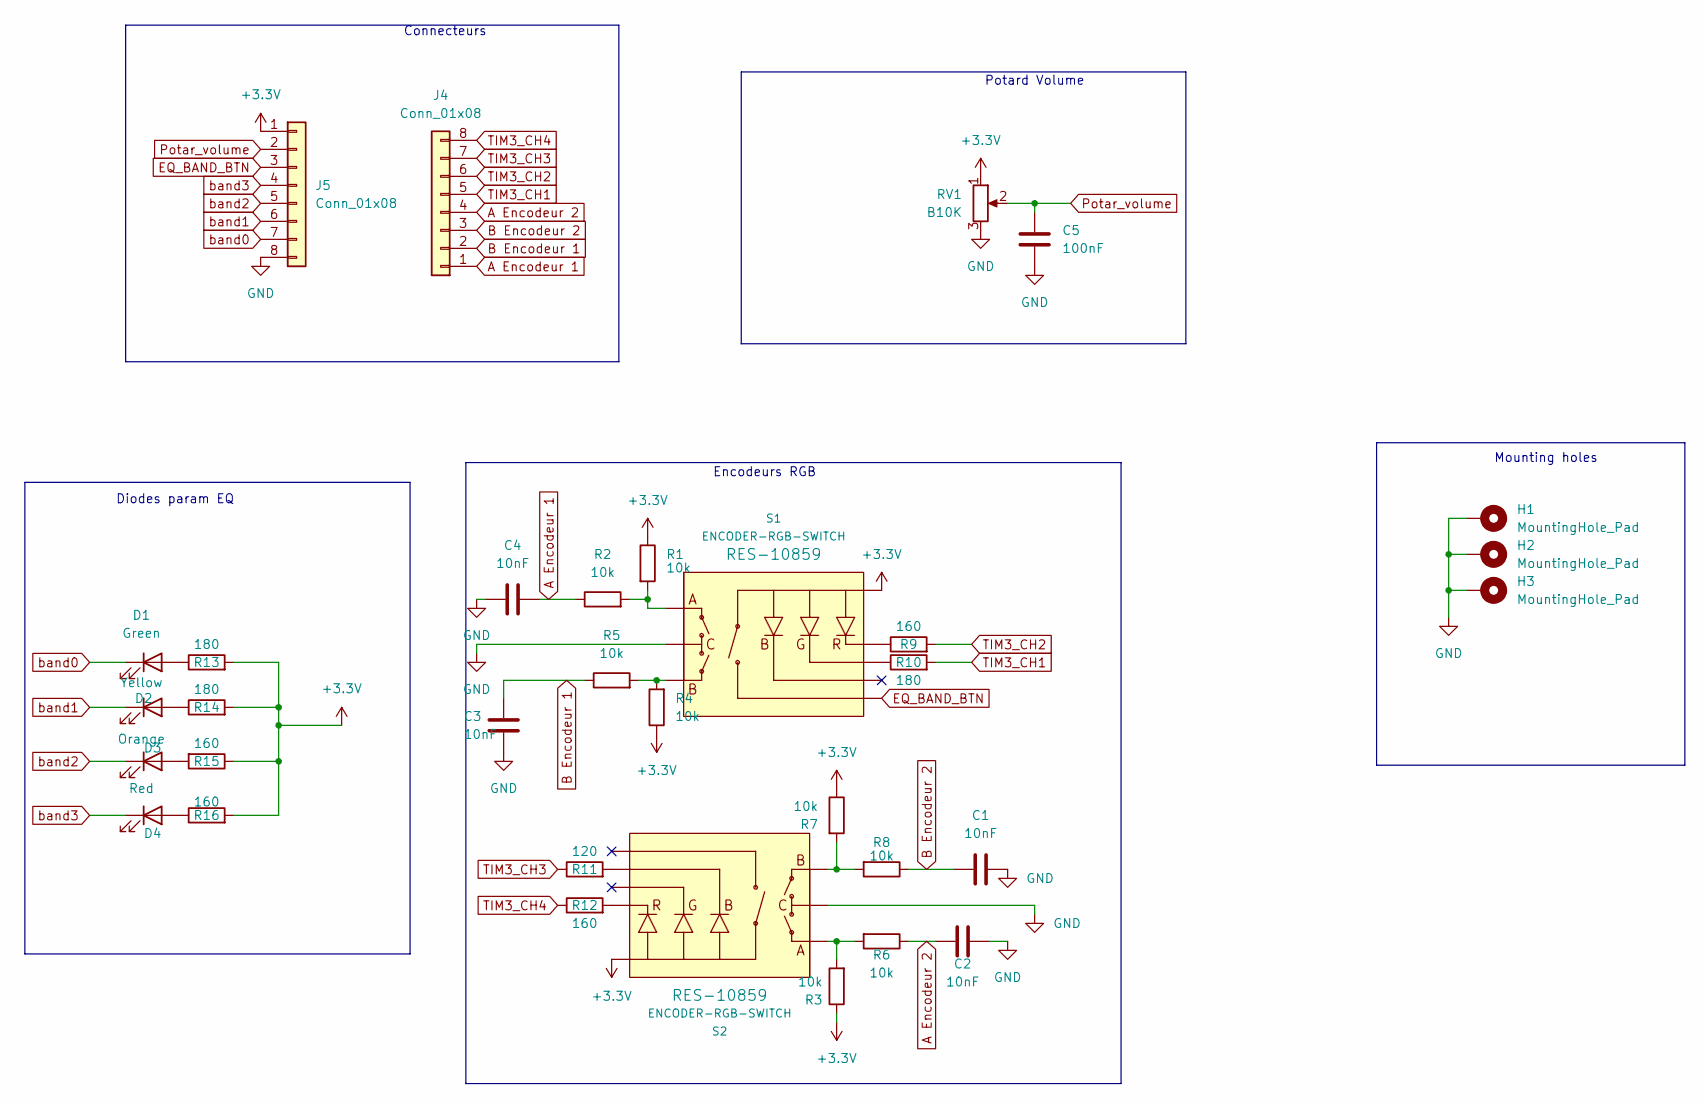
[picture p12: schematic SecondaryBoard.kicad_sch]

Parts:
C1, C2, C3, C4: 10nF; C_0603_1608Metric_Pad1.08x0.95mm_HandSolder
C5: 100nF; C_0603_1608Metric_Pad1.08x0.95mm_HandSolder
D1: Green; LED_D3.0mm
D2: Yellow; LED_D5.0mm
D3: Orange; LED_D5.0mm
D4: Red; LED_D5.0mm
H1, H2, H3: MountingHole_Pad; MountingHole_3.2mm_M3_DIN965_Pad
J4, J5: Conn_01x08; JST_XH_B8B-XH-AM_1x08_P2.50mm_Vertical
R1, R2, R3, R4, R5, R6, R7, R8: 10k; R_0603_1608Metric_Pad0.98x0.95mm_HandSolder
R9, R12, R15, R16: 160; R_0603_1608Metric_Pad0.98x0.95mm_HandSolder
R10, R13, R14: 180; R_0603_1608Metric_Pad0.98x0.95mm_HandSolder
R11: 120; R_0603_1608Metric_Pad0.98x0.95mm_HandSolder
RV1: B10K; Potentiometer_Alpha_RD901F-40-00D_Single_Vertical
S1, S2: ENCODER-RGB-SWITCH; ENCODER_LED_3

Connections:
+3.3V: J5.1, R1.1, R3.1, R4.1, R7.1, R13.2, R14.2, R15.1, R16.2, RV1.1, S1.5, S2.5
A Encodeur 1: C4.2, J4.1, R2.1
A Encodeur 2: C2.2, J4.4, R6.1
B Encodeur 1: C3.2, J4.2, R5.1
B Encodeur 2: C1.2, J4.3, R8.1
EQ_BAND_BTN: J5.3, S1.3
GND: C1.1, C2.1, C3.1, C4.1, C5.1, H1.1, H2.1, H3.1, J5.8, RV1.3, S1.C, S2.C
unnamed: D1.2 (A), R13.1
unnamed: D2.2 (A), R14.1
unnamed: D3.2 (A), R15.2
unnamed: D4.2 (A), R16.1
unnamed: R1.2, R2.2, S1.A
unnamed: R3.2, R6.2, S2.A
unnamed: R4.2, R5.2, S1.B
unnamed: R7.2, R8.2, S2.B
unnamed: R9.1, S1.1
unnamed: R10.1, S1.2
unnamed: R11.2, S2.4
unnamed: R12.2, S2.1
Potar_volume: C5.2, J5.2, RV1.2
TIM3_CH1: J4.5, R10.2
TIM3_CH2: J4.6, R9.2
TIM3_CH3: J4.7, R11.1
TIM3_CH4: J4.8, R12.1
band0: D1.1 (K), J5.7
band1: D2.1 (K), J5.6
band2: D3.1 (K), J5.5
band3: D4.1 (K), J5.4

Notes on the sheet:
Connecteurs
Encodeurs RGB
Diodes param EQ
Potard Volume
Mounting holes

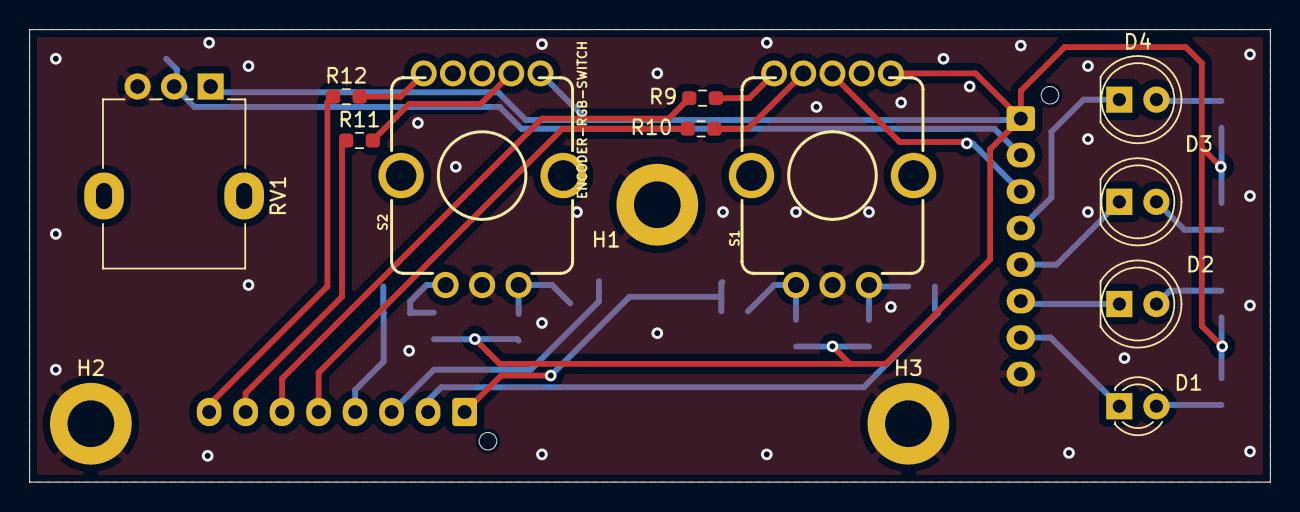
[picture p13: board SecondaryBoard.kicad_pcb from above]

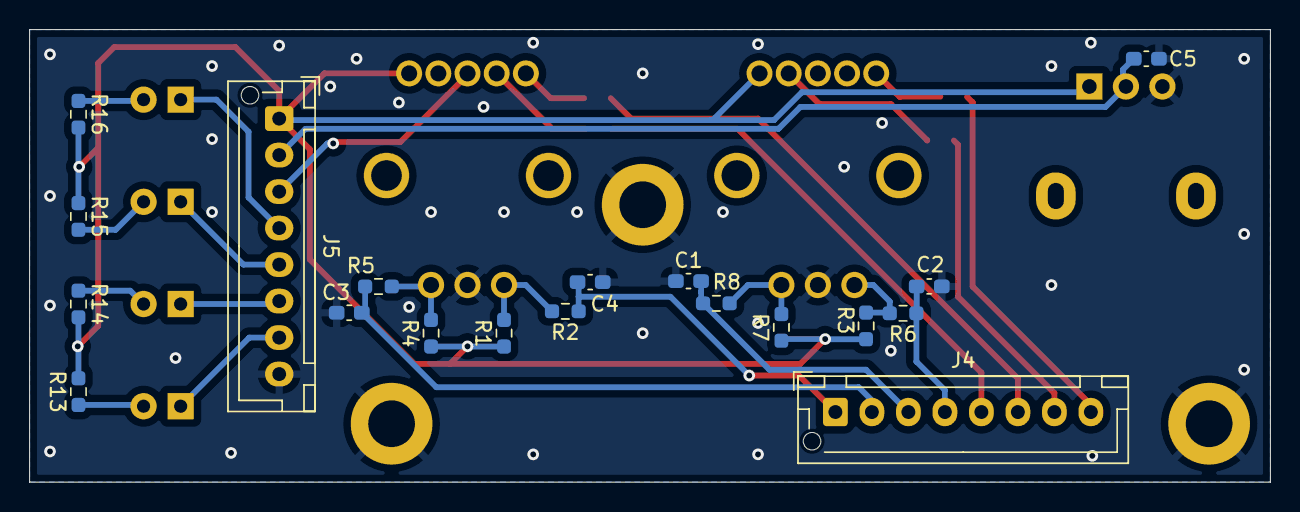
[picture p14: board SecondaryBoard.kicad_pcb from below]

Board: 2 copper layers, 85.0 x 31.0 mm, 33 parts (19 on the bottom side), 28 nets.

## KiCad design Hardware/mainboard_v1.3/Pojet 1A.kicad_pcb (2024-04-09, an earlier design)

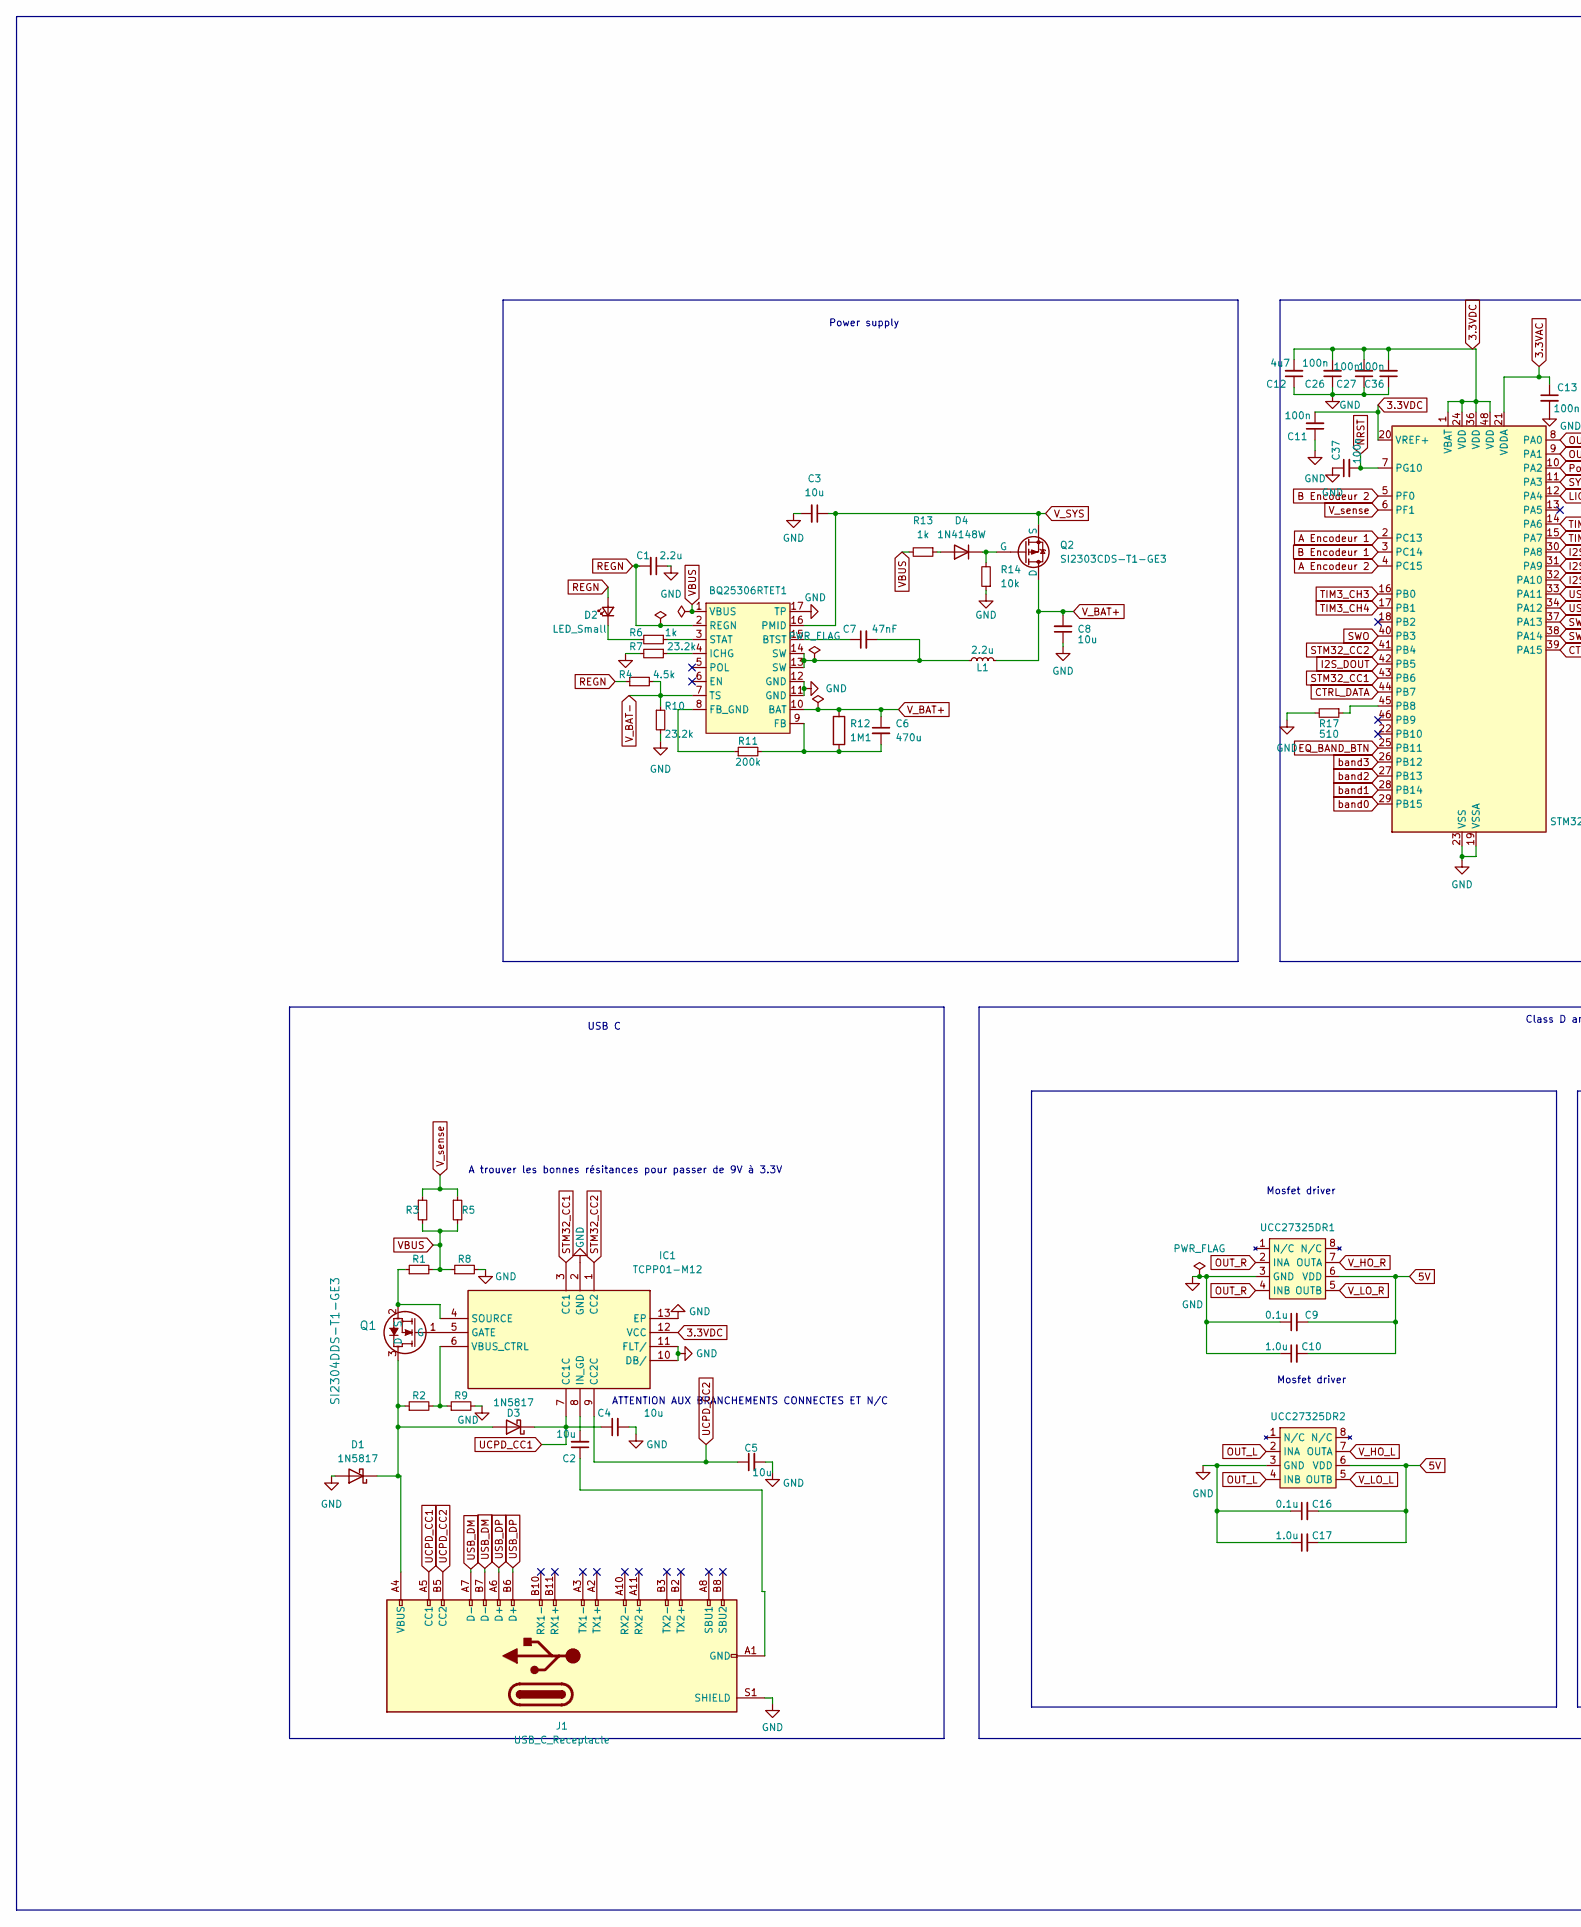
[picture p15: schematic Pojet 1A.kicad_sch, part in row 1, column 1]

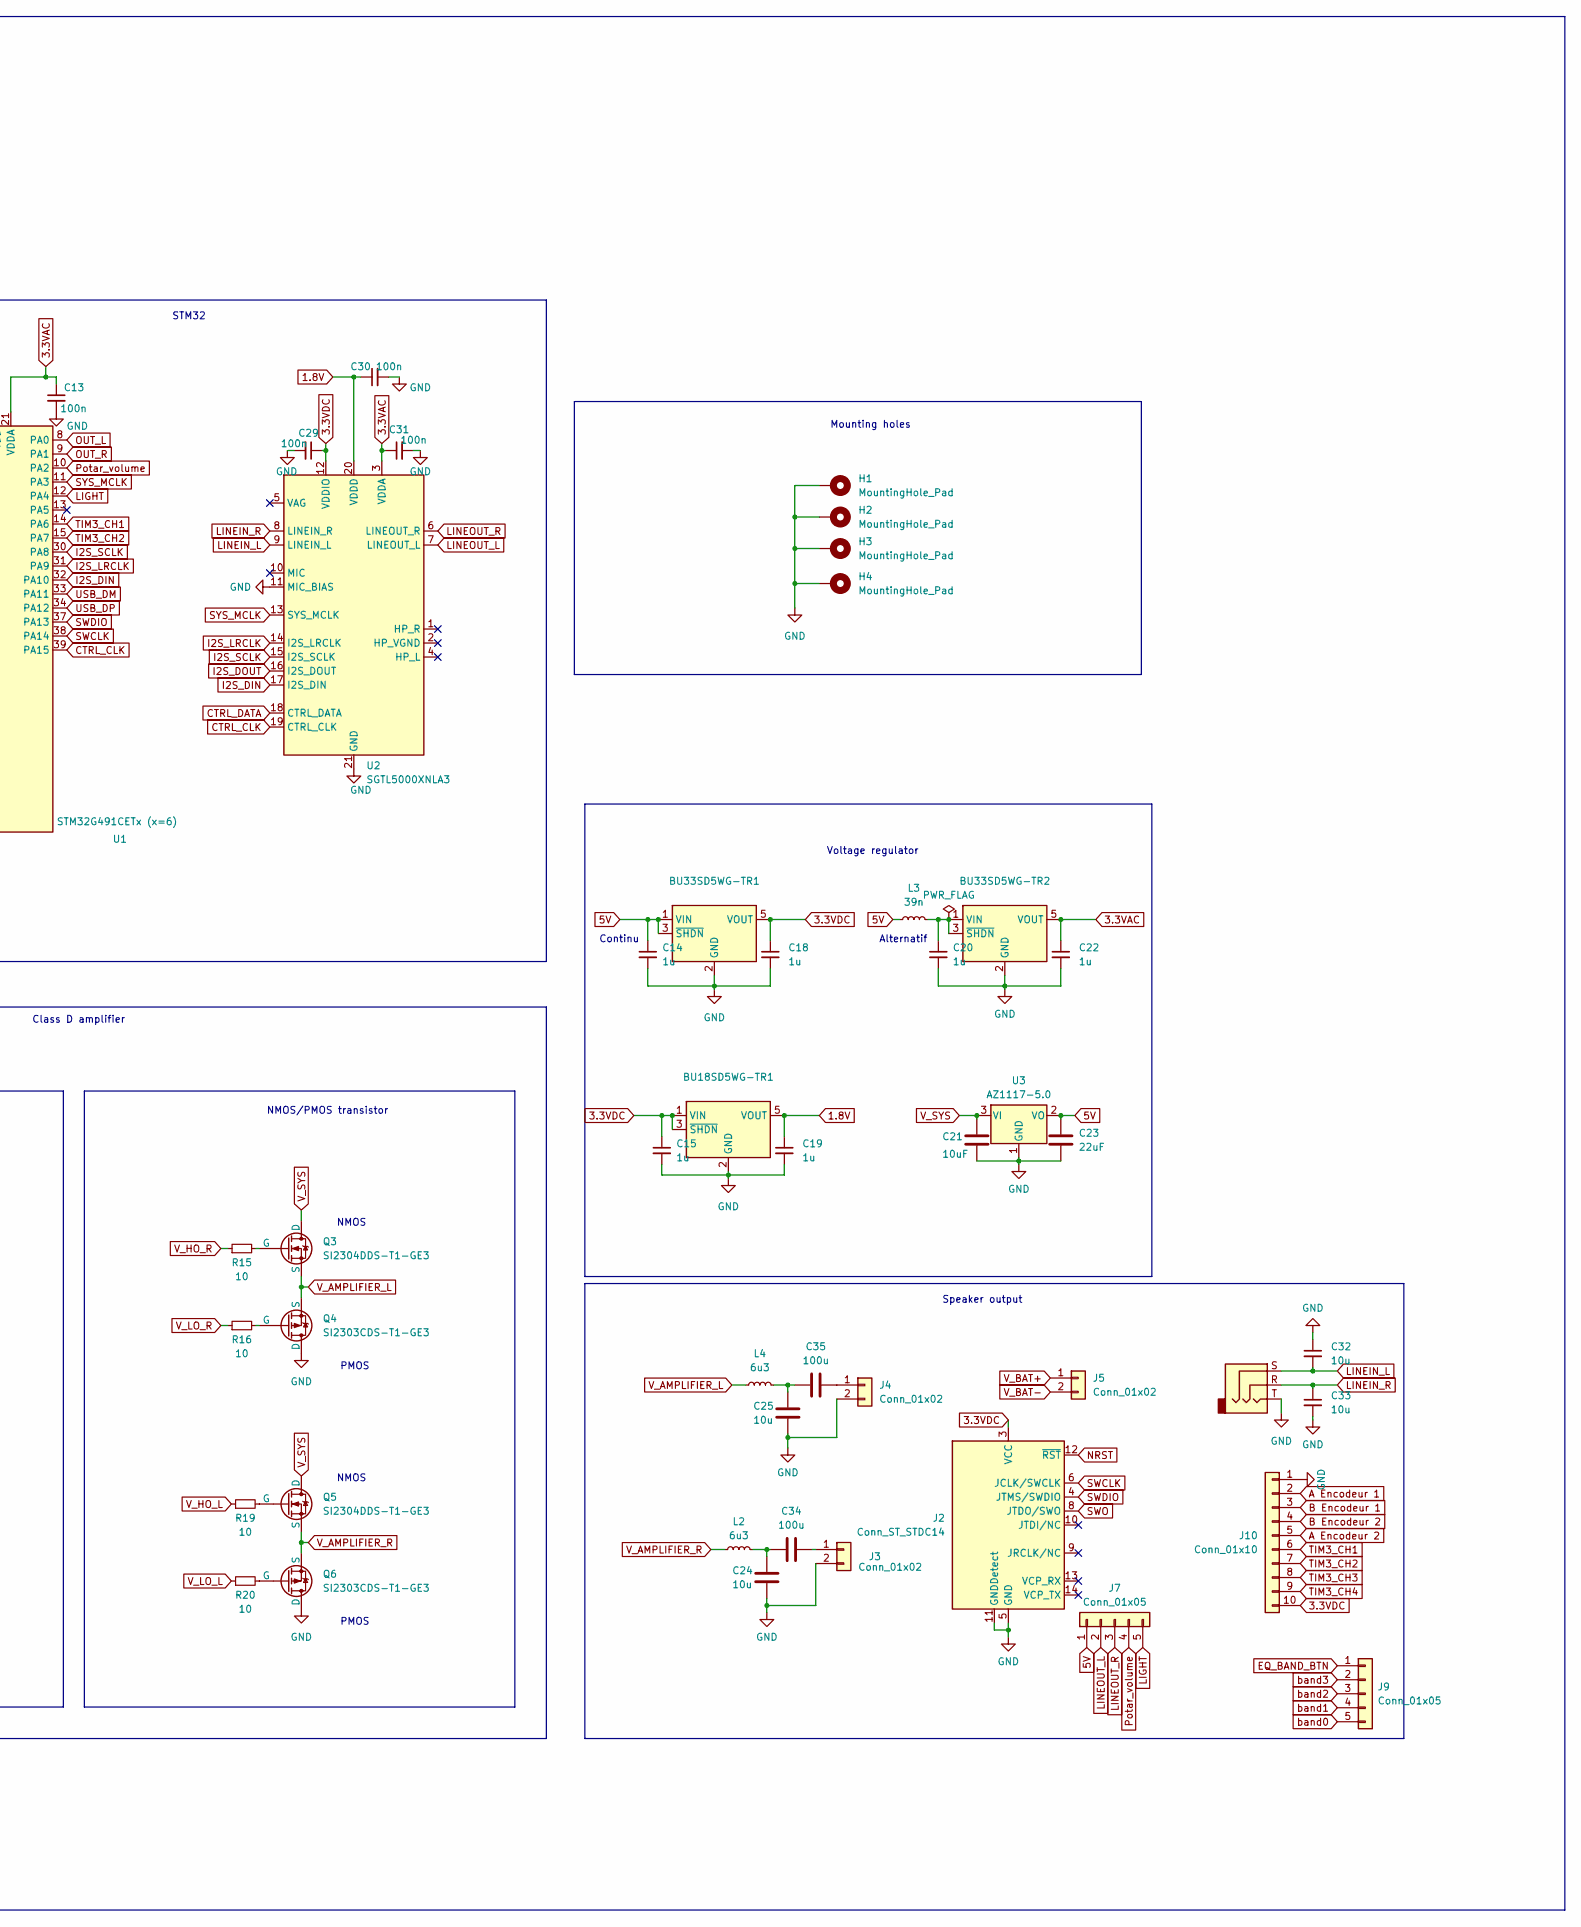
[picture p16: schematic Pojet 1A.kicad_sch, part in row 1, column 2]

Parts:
BQ25306RTET1: WQFN-16-1EP_3x3mm_P0.5mm_EP1.75x1.75mm
BU18SD5WG-TR1, BU33SD5WG-TR1, BU33SD5WG-TR2: LM1117DT-3.3; SOT-23-5
C1: 2.2u; C_0805_2012Metric_Pad1.18x1.45mm_HandSolder
C2, C3, C4, C5, C8, C24, C25, C32, C33: 10u; C_0805_2012Metric_Pad1.18x1.45mm_HandSolder
C6: 470u; C_0805_2012Metric_Pad1.18x1.45mm_HandSolder
C7: 47nF; C_0805_2012Metric_Pad1.18x1.45mm_HandSolder
C9, C16: 0.1u; C_0805_2012Metric_Pad1.18x1.45mm_HandSolder
C10, C17: 1.0u; C_0805_2012Metric_Pad1.18x1.45mm_HandSolder
C11, C13, C26, C27, C29, C30, C31, C36, C37: 100n; C_0805_2012Metric_Pad1.18x1.45mm_HandSolder
C12: 4u7; C_0805_2012Metric_Pad1.18x1.45mm_HandSolder
C14, C15, C18, C19, C20, C22: 1u; C_0805_2012Metric_Pad1.18x1.45mm_HandSolder
C21: 10uF; C_0805_2012Metric_Pad1.18x1.45mm_HandSolder
C23: 22uF; C_0805_2012Metric_Pad1.18x1.45mm_HandSolder
C34, C35: 100u; C_Radial_D5.0mm_H11.0mm_P2.00mm
D1, D3: 1N5817; D_DO-41_SOD81_P10.16mm_Horizontal
D2: LED_Small; LED_D10.0mm
D4: 1N4148W; D_SOD-123
H1, H2, H3, H4: MountingHole_Pad; MountingHole_3.2mm_M3_DIN965_Pad
IC1: TCPP01-M12; LQFN-12-1EP_2x2mm_P0.5mm_EP0.7x0.7mm; Manufacturer_Part_Number TCPP01-M12; Mouser Part Number 511-TCPP01-M12
J1: USB_C_Receptacle; USB_C_Receptacle_GCT_USB4115-03-C
J2: Conn_ST_STDC14; PinHeader_2x07_P1.27mm_Vertical_SMD
J3, J4, J5: Conn_01x02; JST_XH_B2B-XH-A_1x02_P2.50mm_Vertical
J7, J9: Conn_01x05; PinHeader_1x05_P2.54mm_Vertical
J8: AudioJack3; Jack_6.35mm_Neutrik_NJ3FD-V_Vertical
J10: Conn_01x10; PinHeader_1x10_P2.54mm_Vertical
L1: 2.2u; L_0805_2012Metric_Pad1.05x1.20mm_HandSolder
L2, L4: 6u3; L_Vishay_IFSC-1515AH_4x4x1.8mm
L3: 39n; L_0603_1608Metric_Pad1.05x0.95mm_HandSolder
Q1, Q3, Q5: SI2304DDS-T1-GE3; SOT-23
Q2, Q4, Q6: SI2303CDS-T1-GE3; SOT-23
R1, R2, R3, R5, R8, R9: R_0603_1608Metric_Pad0.98x0.95mm_HandSolder
R4: 4.5k; R_0603_1608Metric_Pad0.98x0.95mm_HandSolder
R6, R13: 1k; R_0603_1608Metric_Pad0.98x0.95mm_HandSolder
R7, R10: 23.2k; R_0603_1608Metric_Pad0.98x0.95mm_HandSolder
R11: 200k; R_0603_1608Metric_Pad0.98x0.95mm_HandSolder
R12: 1M1; R_0603_1608Metric_Pad0.98x0.95mm_HandSolder
R14: 10k; R_0603_1608Metric_Pad0.98x0.95mm_HandSolder
R15, R16, R19, R20: 10; R_0603_1608Metric_Pad0.98x0.95mm_HandSolder
R17: 510; R_0603_1608Metric_Pad0.98x0.95mm_HandSolder
U1: STM32G491CETx (x=6); LQFP-48_7x7mm_P0.5mm
U2: SGTL5000XNLA3; QFN-20-1EP_3x3mm_P0.4mm_EP1.65x1.65mm
U3: AZ1117-5.0; SOT-223-3_TabPin2
UCC27325DR1, UCC27325DR2: SOIC-8_3.9x4.9mm_P1.27mm

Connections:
1.8V: BU18SD5WG-TR1.5 (VOUT), C19.1, C30.1, U2.20 (VDDD)
3.3VAC: BU33SD5WG-TR2.5 (VOUT), C13.1, C22.1, C31.1, U1.21 (VDDA), U2.3 (VDDA)
3.3VDC: BU18SD5WG-TR1.1 (VIN), BU18SD5WG-TR1.3 (~SHDN), BU33SD5WG-TR1.5 (VOUT), C11.2, C12.2, C15.1, C18.1, C26.2, C27.2, C29.1, C36.2, IC1.12 (VCC), J2.3 (VCC), J10.10, U1.1 (VBAT), U1.20 (VREF+), U1.24 (VDD), U1.36 (VDD), U1.48 (VDD), U2.12 (VDDIO)
5V: BU33SD5WG-TR1.1 (VIN), BU33SD5WG-TR1.3 (~SHDN), C9.2, C10.2, C14.1, C16.2, C17.2, C23.1, J7.1, L3.1, U3.2 (VO), UCC27325DR1.6 (VDD), UCC27325DR2.6 (VDD)
A Encodeur 1: J10.2, U1.2 (PC13)
A Encodeur 2: J10.5, U1.4 (PC15)
B Encodeur 1: J10.3, U1.3 (PC14)
B Encodeur 2: J10.4, U1.5 (PF0)
CTRL_CLK: U1.39 (PA15), U2.19 (CTRL_CLK)
CTRL_DATA: U1.44 (PB7), U2.18 (CTRL_DATA)
EQ_BAND_BTN: J9.1, U1.25 (PB11)
GND: BQ25306RTET1.11 (GND), BQ25306RTET1.12 (GND), BQ25306RTET1.17 (TP), BU18SD5WG-TR1.2 (GND), BU33SD5WG-TR1.2 (GND), BU33SD5WG-TR2.2 (GND), C1.1, C3.2, C4.2, C5.2, C8.1, C9.1, C10.1, C11.1, C12.1, C13.2, C14.2, C15.2, C16.1, C17.1, C18.2, C19.2, C20.2, C21.2, C22.2, C23.2, C24.2, C25.2, C26.1, C27.1, C29.2, C30.2, C31.2, C32.1, C33.2, C36.1, C37.1, D1.2 (A), H1.1, H2.1, H3.1, H4.1, IC1.2 (GND), IC1.10 (DB/), IC1.11 (FLT/), IC1.13 (EP), J1.S1 (SHIELD), J2.5 (GND), J2.7 (GND), J2.11 (GNDDetect), J3.2, J4.2, J8.T, J10.1, Q4.1 (D), Q6.1 (D), R7.2, R8.2, R9.2, R10.2, R14.1, R17.2, U1.19 (VSSA), U1.23 (VSS), U1.35 (VSS), U1.47 (VSS), U2.11 (MIC_BIAS), U2.21 (GND), U3.1 (GND), UCC27325DR1.3 (GND), UCC27325DR2.3 (GND)
I2S_DIN: U1.32 (PA10), U2.17 (I2S_DIN)
I2S_DOUT: U1.42 (PB5), U2.16 (I2S_DOUT)
I2S_LRCLK: U1.31 (PA9), U2.14 (I2S_LRCLK)
I2S_SCLK: U1.30 (PA8), U2.15 (I2S_SCLK)
LIGHT: J7.5, U1.12 (PA4)
LINEIN_L: C32.2, J8.S, U2.9 (LINEIN_L)
LINEIN_R: C33.1, J8.R, U2.8 (LINEIN_R)
LINEOUT_L: J7.2, U2.7 (LINEOUT_L)
LINEOUT_R: J7.3, U2.6 (LINEOUT_R)
NRST: C37.2, J2.12 (~RST), U1.7 (PG10)
unnamed: BQ25306RTET1.15 (BTST), C7.1
unnamed: BQ25306RTET1.9 (FB), C6.2, R11.2, R12.2
unnamed: BQ25306RTET1.8 (FB_GND), R11.1
unnamed: BQ25306RTET1.4 (ICHG), R7.1
unnamed: BQ25306RTET1.3 (STAT), R6.1
unnamed: BQ25306RTET1.13 (SW), BQ25306RTET1.14 (SW), C7.2, L1.1
unnamed: BU33SD5WG-TR2.1 (VIN), BU33SD5WG-TR2.3 (~SHDN), C20.1, L3.2
unnamed: C2.1, J1.A1 (GND), J1.A12 (GND), J1.B1 (GND), J1.B12 (GND)
unnamed: C24.1, C34.1, L2.2
unnamed: C25.1, C35.1, L4.2
unnamed: D1.1 (K), D3.2 (A), J1.A4 (VBUS), J1.A9 (VBUS), J1.B4 (VBUS), J1.B9 (VBUS), Q1.3 (D), R2.1
unnamed: D2.1 (K), R6.2
unnamed: D4.2 (A), R13.1
unnamed: D4.1 (K), Q2.2 (G), R14.2
unnamed: IC1.5 (GATE), Q1.1 (G)
unnamed: C2.2, IC1.8 (IN_GD)
unnamed: IC1.4 (SOURCE), Q1.2 (S), R1.1
unnamed: IC1.6 (VBUS_CTRL), R2.2, R9.1
unnamed: C34.2, J3.1
unnamed: C35.2, J4.1
unnamed: Q3.2 (G), R15.2
unnamed: Q4.2 (G), R16.2
unnamed: Q5.2 (G), R19.2
unnamed: Q6.2 (G), R20.2
unnamed: R17.1, U1.45 (PB8)
OUT_L: U1.8 (PA0), UCC27325DR2.2 (INA), UCC27325DR2.4 (INB)
OUT_R: U1.9 (PA1), UCC27325DR1.2 (INA), UCC27325DR1.4 (INB)
Potar_volume: J7.4, U1.10 (PA2)
REGN: BQ25306RTET1.2 (REGN), C1.2, D2.2 (A), R4.1
STM32_CC1: IC1.3 (CC1), U1.43 (PB6)
STM32_CC2: IC1.1 (CC2), U1.41 (PB4)
SWCLK: J2.6 (JCLK/SWCLK), U1.38 (PA14)
SWDIO: J2.4 (JTMS/SWDIO), U1.37 (PA13)
SWO: J2.8 (JTDO/SWO), U1.40 (PB3)
SYS_MCLK: U1.11 (PA3), U2.13 (SYS_MCLK)
TIM3_CH1: J10.6, U1.14 (PA6)
TIM3_CH2: J10.7, U1.15 (PA7)
TIM3_CH3: J10.8, U1.16 (PB0)
TIM3_CH4: J10.9, U1.17 (PB1)
UCPD_CC1: C4.1, D3.1 (K), IC1.7 (CC1C), J1.A5 (CC1)
UCPD_CC2: C5.1, IC1.9 (CC2C), J1.B5 (CC2)
USB_DM: J1.A7 (D-), J1.B7 (D-), U1.33 (PA11)
USB_DP: J1.A6 (D+), J1.B6 (D+), U1.34 (PA12)
VBUS: BQ25306RTET1.1 (VBUS), R1.2, R3.2, R5.2, R8.1, R13.2
V_AMPLIFIER_L: L4.1, Q3.3 (S), Q4.3 (S)
V_AMPLIFIER_R: L2.1, Q5.3 (S), Q6.3 (S)
V_BAT+: BQ25306RTET1.10 (BAT), C6.1, C8.2, J5.1, L1.2, Q2.1 (D), R12.1
V_BAT-: BQ25306RTET1.7 (TS), J5.2, R4.2, R10.1
V_HO_L: R19.1, UCC27325DR2.7 (OUTA)
V_HO_R: R15.1, UCC27325DR1.7 (OUTA)
V_LO_L: R20.1, UCC27325DR2.5 (OUTB)
V_LO_R: R16.1, UCC27325DR1.5 (OUTB)
V_SYS: BQ25306RTET1.16 (PMID), C3.1, C21.1, Q2.3 (S), Q3.1 (D), Q5.1 (D), U3.3 (VI)
V_sense: R3.1, R5.1, U1.6 (PF1)
band0: J9.5, U1.29 (PB15)
band1: J9.4, U1.28 (PB14)
band2: J9.3, U1.27 (PB13)
band3: J9.2, U1.26 (PB12)

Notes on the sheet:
Speaker output
A trouver les bonnes résitances pour passer de 9V à 3.3V
PMOS
NMOS
ATTENTION AUX BRANCHEMENTS CONNECTES ET N/C
NMOS/PMOS transistor
Continu
Mounting holes
Voltage regulator
USB C
Alternatif
Mosfet driver
STM32
Class D amplifier
Power supply

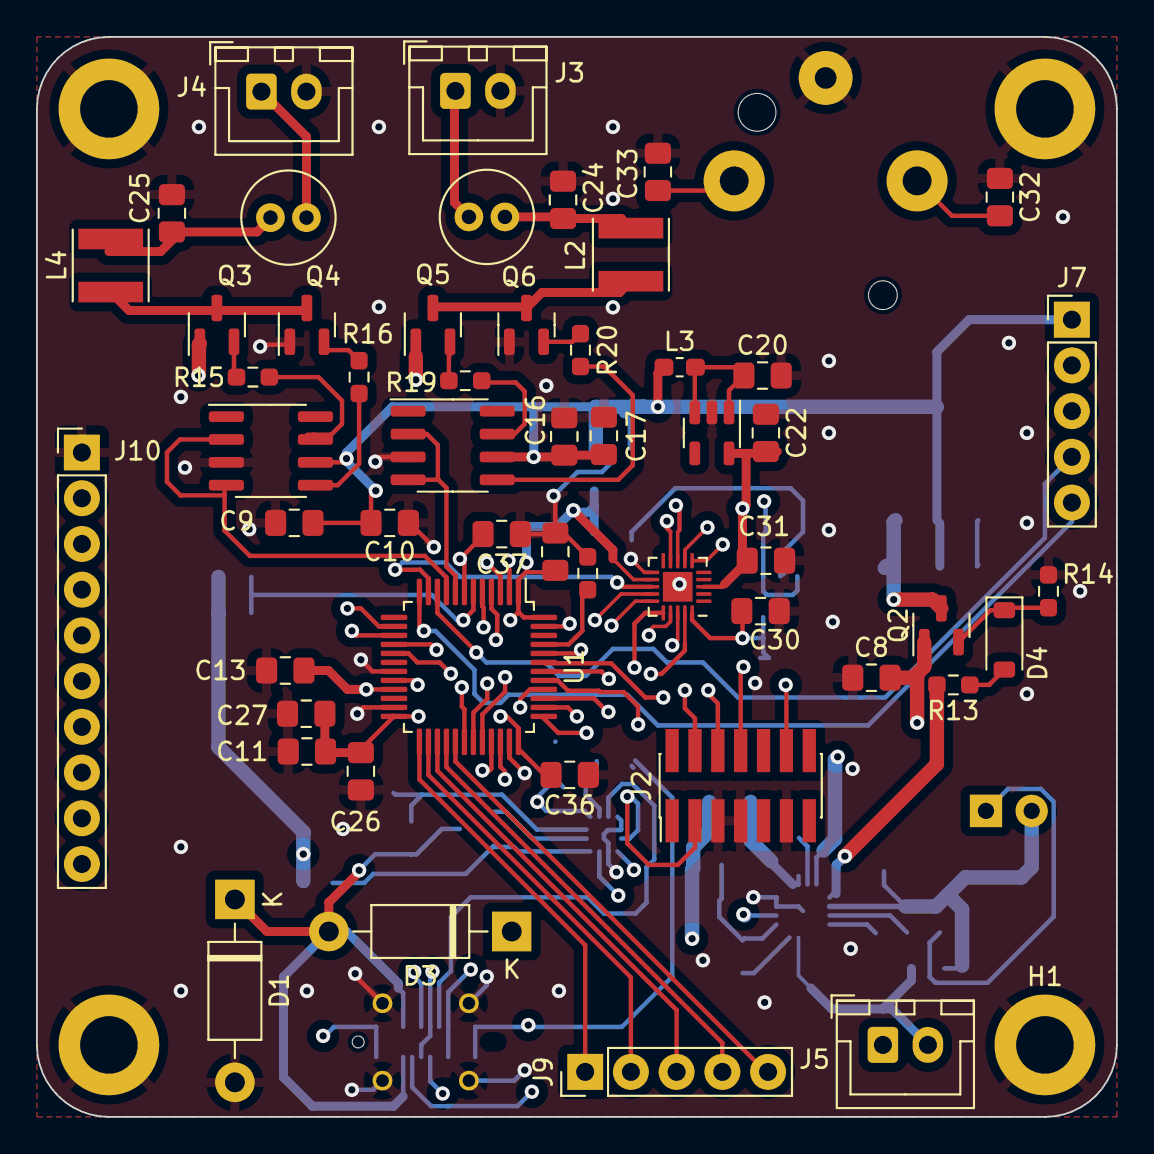
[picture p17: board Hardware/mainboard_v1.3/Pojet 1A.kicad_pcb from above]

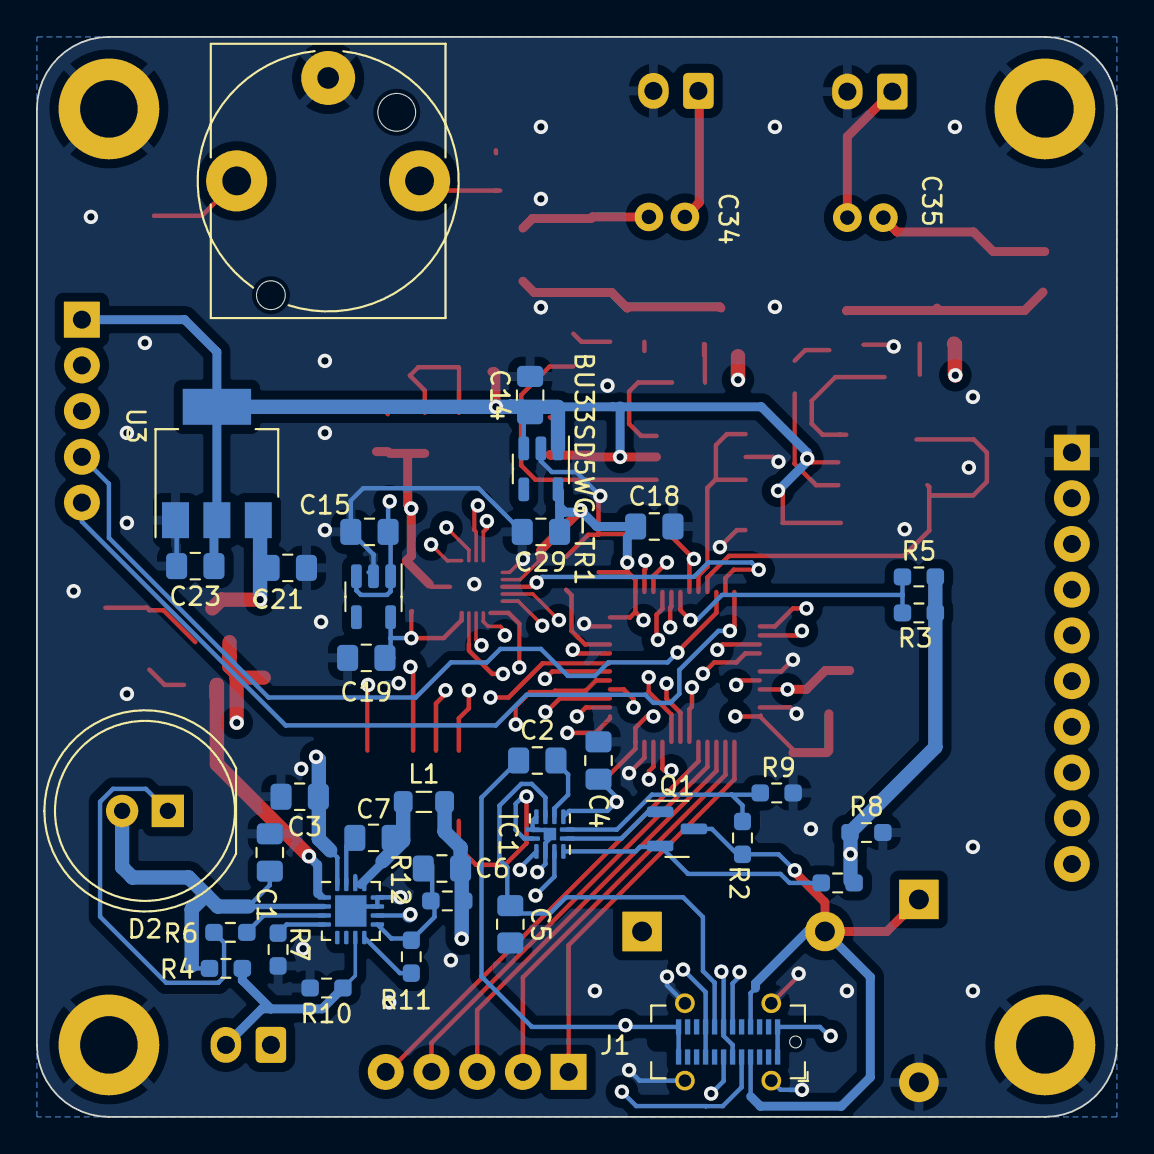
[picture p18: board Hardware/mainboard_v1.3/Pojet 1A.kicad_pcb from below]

Board: 4 copper layers, 60.0 x 60.0 mm, 92 parts (36 on the bottom side), 80 nets.

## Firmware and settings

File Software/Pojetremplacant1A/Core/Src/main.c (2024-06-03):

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
/* Includes ------------------------------------------------------------------*/
#include "main.h"

ADC_HandleTypeDef hadc1;

TIM_HandleTypeDef htim2;
TIM_HandleTypeDef htim3;

UART_HandleTypeDef huart2;

/* USER CODE BEGIN PV */
int Encoder;
int button=1;
int maxValue = 65535;
int volume(int);
int Read_Potentiometer(void);
/* USER CODE END PV */

void SystemClock_Config(void);
static void MX_GPIO_Init(void);
static void MX_USART2_UART_Init(void);
static void MX_TIM3_Init(void);
static void MX_ADC1_Init(void);
static void MX_TIM2_Init(void);
/* USER CODE BEGIN 0 */
#ifdef __GNUC__
#define PUTCHAR_PROTOTYPE int __io_putchar(int ch)
#define GETCHAR_PROTOTYPE int __io_getchar(void)
#else
#define PUTCHAR_PROTOTYPE int fputc(int ch, FILE *f)
#define GETCHAR_PROTOTYPE int fgetc(FILE *f)
#endif


PUTCHAR_PROTOTYPE
{
	HAL_UART_Transmit(&huart2, (uint8_t *)&ch, 1, HAL_MAX_DELAY);
	return ch;
}

int volume(int potar){
	int nombrevaleurs=(int)(4096/128);
	for(int multiple=0; multiple<128; multiple++){
		if(potar>nombrevaleurs*multiple-1 && potar < nombrevaleurs * multiple + nombrevaleurs){
			return multiple;
		}
	}
	return 64;
}

int Read_Potentiometer(void)
{
    HAL_ADC_Start(&hadc1);
    if (HAL_ADC_PollForConversion(&hadc1, HAL_MAX_DELAY) == HAL_OK)
    {
        return HAL_ADC_GetValue(&hadc1);
    }
    return 0;
}

void HAL_GPIO_EXTI_Callback(uint16_t GPIO_Pin)
{
    int A = HAL_GPIO_ReadPin(A_GPIO_Port, A_Pin);
    int B = HAL_GPIO_ReadPin(B_GPIO_Port, B_Pin);
    if (GPIO_Pin == button_Pin)
    {
    	button=1-button;
    }

    if (GPIO_Pin == A_Pin)
    {
        if (A == 1)
        {
            if (B == 0)
            {
                Encoder += 1000;
            }
        }
        if (Encoder > maxValue)
                Encoder = maxValue;
            else if (Encoder < 0)
                Encoder = 0;
    }
    else if (GPIO_Pin == B_Pin)
    {
        if (B == 1)
        {
            if (A == 0)
            {
                Encoder += -1000;
            }
        }
        if (Encoder > maxValue)
                Encoder = maxValue;
            else if (Encoder < 0)
                Encoder = 0;
    }

	  __HAL_TIM_SET_COMPARE(&htim2, TIM_CHANNEL_1,65535-Encoder );
	  __HAL_TIM_SET_COMPARE(&htim3, TIM_CHANNEL_1,Encoder );
}
/* USER CODE END 0 */

/**
  * @brief  The application entry point.
  * @retval int
  */
int main(void)
{

  /* MCU Configuration--------------------------------------------------------*/

  /* Reset of all peripherals, Initializes the Flash interface and the Systick. */
  HAL_Init();

  /* Configure the system clock */
  SystemClock_Config();

  /* Initialize all configured peripherals */
  MX_GPIO_Init();
  MX_USART2_UART_Init();
  MX_TIM3_Init();
  MX_ADC1_Init();
  MX_TIM2_Init();
  /* USER CODE BEGIN 2 */
  HAL_TIM_PWM_Start(&htim3, TIM_CHANNEL_1);
  HAL_TIM_PWM_Start(&htim2, TIM_CHANNEL_1);
  HAL_TIM_PWM_Start(&htim3, TIM_CHANNEL_2);
  /* USER CODE END 2 */

  /* Infinite loop */
  /* USER CODE BEGIN WHILE */
  while (1)
  {
	  int potar_value = Read_Potentiometer();
	  int delay = volume(potar_value);
	  __HAL_TIM_SET_COMPARE(&htim3, TIM_CHANNEL_2,button*maxValue );
	  if(button==1){
		  HAL_GPIO_WritePin(LED0_GPIO_Port,LED0_Pin,0);
		  HAL_Delay(delay);
		  HAL_GPIO_WritePin(LED0_GPIO_Port,LED0_Pin,1);
		  HAL_GPIO_WritePin(LED1_GPIO_Port,LED1_Pin,0);
		  HAL_Delay(delay);
		  HAL_GPIO_WritePin(LED1_GPIO_Port,LED1_Pin,1);
		  HAL_GPIO_WritePin(LED2_GPIO_Port,LED2_Pin,0);
		  HAL_Delay(delay);
		  HAL_GPIO_WritePin(LED2_GPIO_Port,LED2_Pin,1);
		  HAL_GPIO_WritePin(LED3_GPIO_Port,LED3_Pin,0);
		  HAL_Delay(delay);
		  HAL_GPIO_WritePin(LED3_GPIO_Port,LED3_Pin,1);
	  }
	  if(button==0){
		  HAL_GPIO_WritePin(LED3_GPIO_Port,LED3_Pin,0);
		  HAL_Delay(delay);
		  HAL_GPIO_WritePin(LED3_GPIO_Port,LED3_Pin,1);
		  HAL_GPIO_WritePin(LED2_GPIO_Port,LED2_Pin,0);
		  HAL_Delay(delay);
		  HAL_GPIO_WritePin(LED2_GPIO_Port,LED2_Pin,1);
		  HAL_GPIO_WritePin(LED1_GPIO_Port,LED1_Pin,0);
		  HAL_Delay(delay);
		  HAL_GPIO_WritePin(LED1_GPIO_Port,LED1_Pin,1);
		  HAL_GPIO_WritePin(LED0_GPIO_Port,LED0_Pin,0);
		  HAL_Delay(delay);
		  HAL_GPIO_WritePin(LED0_GPIO_Port,LED0_Pin,1);
	  }
    /* USER CODE END WHILE */

    /* USER CODE BEGIN 3 */
  }
  /* USER CODE END 3 */
}

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


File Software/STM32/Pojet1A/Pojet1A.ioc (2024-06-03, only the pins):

Mcu.UserName=STM32G491CETx
PA0.GPIO_Label=Out_L
PA0.Signal=S_TIM2_CH1
PA1.GPIO_Label=Out_R
PA1.Signal=S_TIM2_CH2
PA10.Signal=SAI1_SD_A
PA11.Signal=USB_DM
PA12.Signal=USB_DP
PA13.Signal=SYS_JTMS-SWDIO
PA14.Signal=SYS_JTCK-SWCLK
PA15.Signal=I2C1_SCL
PA2.GPIO_Label=pot_volume
PA2.Signal=ADC1_IN3
PA3.Signal=SAI1_MCLK_A
PA4.GPIO_Label=light
PA4.Signal=GPIO_Output
PA6.Signal=S_TIM3_CH1
PA7.Signal=S_TIM3_CH2
PA8.Signal=SAI1_SCK_A
PA9.Signal=SAI1_FS_A
PB0.Signal=S_TIM3_CH3
PB1.Signal=S_TIM3_CH4
PB10.Signal=USART3_TX
PB11.GPIO_Label=eq_band_btn
PB11.Signal=GPXTI11
PB12.GPIO_Label=band3
PB12.Signal=GPIO_Output
PB13.GPIO_Label=band2
PB13.Signal=GPIO_Output
PB14.GPIO_Label=band1
PB14.Signal=GPIO_Output
PB15.GPIO_Label=band0
PB15.Signal=GPIO_Output
PB3.Signal=SYS_JTDO-SWO
PB4.Signal=UCPD1_CC2
PB5.Signal=SAI1_SD_B
PB6.Signal=UCPD1_CC1
PB7.Signal=I2C1_SDA
PB8-BOOT0.Signal=USART3_RX
PC13.GPIO_Label=A1
PC13.Signal=GPXTI13
PC14-OSC32_IN.GPIO_Label=A2
PC14-OSC32_IN.Signal=GPXTI14
PC15-OSC32_OUT.GPIO_Label=B1
PC15-OSC32_OUT.Signal=GPXTI15
PF0-OSC_IN.GPIO_Label=B2
PF0-OSC_IN.Signal=GPXTI0
PF1-OSC_OUT.GPIO_Label=V_sense
PF1-OSC_OUT.Signal=ADC2_IN10

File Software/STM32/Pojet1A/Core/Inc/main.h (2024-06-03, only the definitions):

#define A1_Pin GPIO_PIN_13
#define A1_GPIO_Port GPIOC
#define A2_Pin GPIO_PIN_14
#define A2_GPIO_Port GPIOC
#define B1_Pin GPIO_PIN_15
#define B1_GPIO_Port GPIOC
#define B2_Pin GPIO_PIN_0
#define B2_GPIO_Port GPIOF
#define V_sense_Pin GPIO_PIN_1
#define V_sense_GPIO_Port GPIOF
#define Out_L_Pin GPIO_PIN_0
#define Out_L_GPIO_Port GPIOA
#define Out_R_Pin GPIO_PIN_1
#define Out_R_GPIO_Port GPIOA
#define pot_volume_Pin GPIO_PIN_2
#define pot_volume_GPIO_Port GPIOA
#define light_Pin GPIO_PIN_4
#define light_GPIO_Port GPIOA
#define eq_band_btn_Pin GPIO_PIN_11
#define eq_band_btn_GPIO_Port GPIOB
#define band3_Pin GPIO_PIN_12
#define band3_GPIO_Port GPIOB
#define band2_Pin GPIO_PIN_13
#define band2_GPIO_Port GPIOB
#define band1_Pin GPIO_PIN_14
#define band1_GPIO_Port GPIOB
#define band0_Pin GPIO_PIN_15
#define band0_GPIO_Port GPIOB

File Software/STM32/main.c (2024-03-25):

#include "project.h"

extern param_sgtl_t param_son;
param_son.band0_freq=450;
param_son.band1_freq=1900;
param_son.band2_freq=5500;
param_son.band3_freq=12000;
param_son.band0_gain=0;
param_son.band1_gain=0;
param_son.band2_gain=0;
param_son.band3_gain=0;

int main()
{
    
    modificationvaleur(1,850,1,0);

    return 0;
}

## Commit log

2024-02-26 Schema de l'ampli class D
    [Amplifierv0.2.kicad_pcb, Amplifierv0.2.kicad_sch]
2024-02-27 Update ToBuy.txt
    MOSFET Driver et USB C power Delivery IC
2024-02-27 Update and rename oldnotes.txt to reviewedNotes.txt
    Notes détaillants les sous-systèmes du projet
2024-03-02 update schematic ampli
    [Ampli_Stage.kicad_sch, Amplifierv0.2.kicad_sch]
2024-03-02 uploaded schematic v2
    [Amplifierv0.2 (2).kicad_sch]
2024-03-02 updated amplifier schematic v3
    [Amplifierv0.2 (2).kicad_sch]
2024-03-05 Update and rename STM32golas.txt to STM32golas.txt
2024-03-05 Projet CubeIDE implémentation des IOs
2024-03-05 Update and rename STM32golas.txt to STM32goals.txt
2024-03-11 Delete datasheets/Transistor Mos IRF640.PDF
    Pas besoin de ce Mos
2024-03-11 Add files via upload
    Le Mosfet Driver d'origine
2024-03-11 Create STM32G491KBT6
2024-03-18 Ampli v5
    [Amplifierv0.2 (2) (1) (1).kicad_sch]
2024-03-18 Create code en cours pr la modificatino de la valeur par la roue
2024-03-25 Update and rename code en cours pr la modificatino de la valeur par la roue to project.c
2024-03-25 Update and rename Software/STM32/project.c to Software/modif_sgtl.c
2024-03-25 filter eq
    fonctions qui effectuent une équalisation
2024-03-25 Update and rename Software/STM32/filter.c to Software/STM32/EqualisationandVolume/filter.c
2024-03-25 Update and rename filter.c to filter.c
2024-03-25 Update and rename Software/STM32/filter.h to Software/STM32/EqAndVol/filter.h
2024-03-25 Ampli v6
    [Amplifierv0.2 (2) (1) (1).kicad_sch]
2024-03-28 stm32 modifs
2024-03-30 apli v7
    [Amplifierv0.2 (2) (1) (1).kicad_sch]
2024-04-04 mainboard 1.1 in progress
    editing capacity values and adding of the STM32 programing connector
    [Amplifierv0.2 (2) (1) (1).kicad_sch, Pojet 1A.kicad_pcb, Pojet 1A.kicad_sch]
2024-04-04 new relase of the board
    [Pojet 1A.kicad_pcb, Pojet 1A.kicad_sch]
2024-04-05 Add files via upload
    DE
    [Pojet 1A.kicad_pcb, Pojet 1A.kicad_sch]
2024-04-05 PCB avec les vias traversants
    [Pojet 1A.kicad_pcb, Pojet 1A.kicad_sch]
2024-04-05 hey
    update
    [Pojet 1A.kicad_pcb, Pojet 1A.kicad_sch]
2024-04-05 Add files via upload
    update 1 error
    [Pojet 1A.kicad_pcb]
2024-04-29 Secondary Board v1 Schematic
    [SecondaryBoard.kicad_pcb, SecondaryBoard.kicad_sch]
2024-04-29 update pff
    [SecondaryBoard.kicad_sch]
2024-04-29 explicit name
    [Pojet 1A.kicad_pcb, Pojet 1A.kicad_sch]
2024-04-29 PCB update still some errors
    [Pojet 1A.kicad_pcb, Pojet 1A.kicad_sch, USB4180-03-0120-C_REVA.step]
2024-04-30 It's good few mistakes but not real ones,
    [Pojet 1A.kicad_pcb, Pojet 1A.kicad_sch, USB4180-03-0120-C_REVA.step]
2024-04-30 Edit
    Remise en cohérence du placement de certains composants(R C) pas grands chose d'importants
    [Pojet 1A.kicad_pcb, Pojet 1A.kicad_sch, USB4180-03-0120-C_REVA.step]
2024-05-03 Finished Update
    [SecondaryBoard.kicad_pcb, SecondaryBoard.kicad_sch]
2024-05-06 little vias edit and gerber plot
    [SecondaryBoard.kicad_pcb, SecondaryBoard.kicad_sch]
2024-05-06 Adding gerber files
    [Pojet 1A-B_Cu.gbr, Pojet 1A-B_Mask.gbr, Pojet 1A-B_Paste.gbr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]
2024-05-07 last gerber vias and track size edits
    [SecondaryBoard.kicad_pcb]
2024-05-23 Final edit for building conformity
    [SecondaryBoard.kicad_pcb]
2024-05-24 Stable with filters and leds Handling
    Sorry for the 7z format I had no choice file was too big
2024-05-27 Encoder datasheet
2024-06-03 final sorting
    [Amplifierv0.2 (2) (1) (1).kicad_sch, Pojet 1A version victor.kicad_sch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]

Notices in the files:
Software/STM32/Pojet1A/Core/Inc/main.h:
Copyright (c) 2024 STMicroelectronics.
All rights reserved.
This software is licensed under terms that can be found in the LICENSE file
